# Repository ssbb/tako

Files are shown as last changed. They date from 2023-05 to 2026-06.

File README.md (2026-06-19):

# Tako

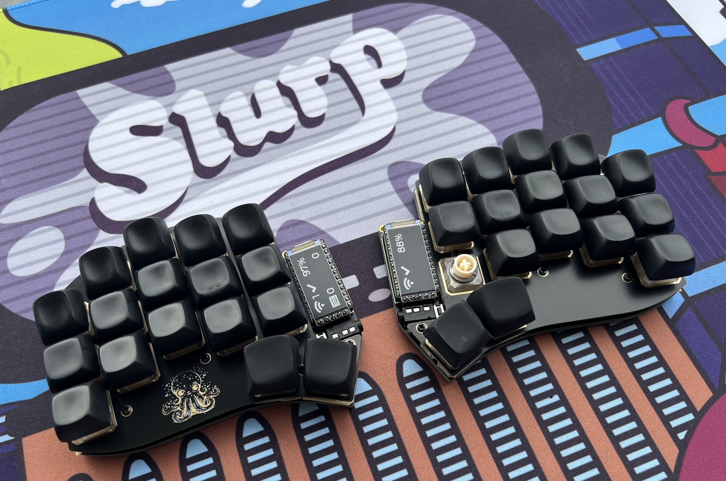
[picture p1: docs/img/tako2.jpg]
Tako Keyboard

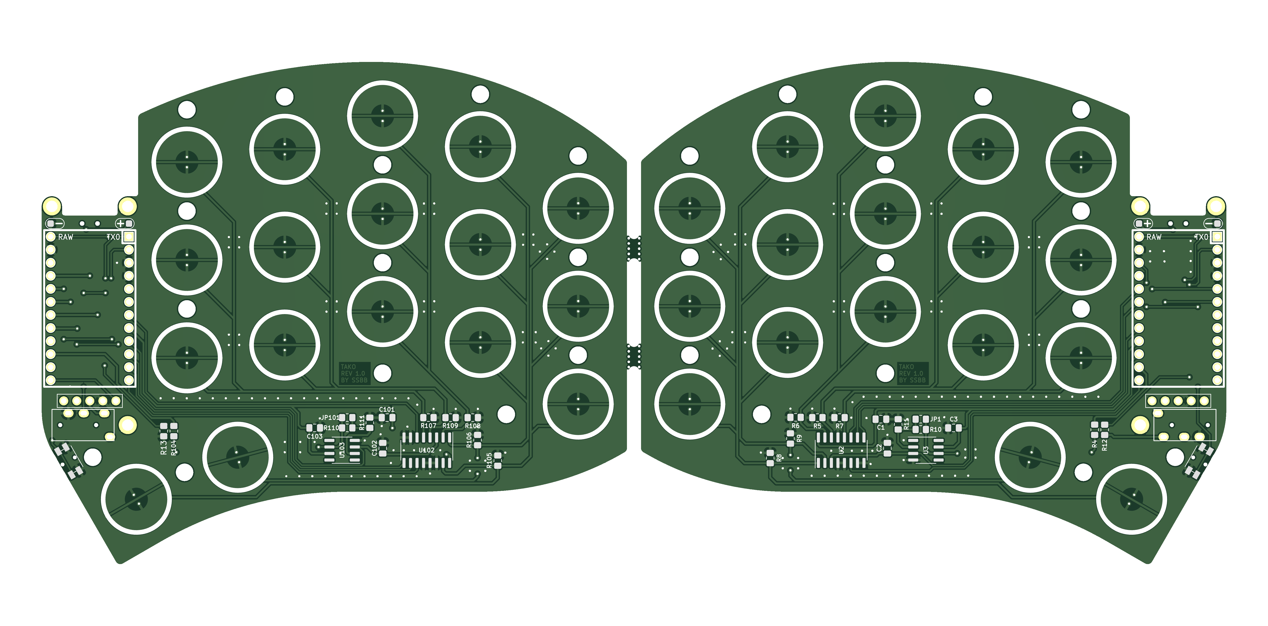
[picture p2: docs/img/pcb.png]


<span>
  
  <a href="https://github.com/ssbb/tako/releases">
    
    
  </a>
  
</span>

Tako is a vertical stagger split keyboard with electrostatic capacitive (EC) non-contact switches.

## Bill Of Materials (BOM)

### Production Files

Depending on which parts you are going to use, make sure to select the proper top plate (OG or NIZ). Ensure you use the correct thickness - the **OG (OEM, Deskeys, etc) plate should be 1.2mm**, and the NIZ should be 1.6mm!

### MCU

RP2040-based boards should be used for wired build - Liatris, Frood, Sea-Picro, Splinky, [etc](https://github.com/qmk/qmk_firmware/blob/master/docs/platformdev_rp2040.md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).

**ATmega32U4 (Pro Micro) won't work.**

#### Wireless

For a wireless build, you can use [nice!nano](https://nicekeyboards.com/nice-nano/). Keep in mind that EC matrix consume significantly more power than mechanical keyboards. An 80mAh battery placed under the MCU will last for about a day only. I don't have exact numbers yet (still waiting for a power profiler), but you will likely need to use a larger battery. Consider using longer standoffs with a 3D-printed or acrylic spacer between the PCB and the bottom plate, and place the battery there.

### Display

5 pins for [nice!view](https://nicekeyboards.com/nice-view/) are exposed. 128x32 OLED can be used on first 4 pins but won't be perfectly centered.

### Components

| Component | Package | Amount | Details |
|---|---|---|---|
| OPA350 | SOIC-8 / SOP-8 | 2 | [LCSC](https://www.lcsc.com/product-detail/_Texas-Instruments-_C13388.html) |
| 74HC4051 | SOIC-8 / SOP-8 | 2 | [LCSC](https://www.lcsc.com/product-detail/_Nexperia-_C9386.html) |
| 100nF Capacitor | 0805 | 4 | [LCSC](https://www.lcsc.com/product-detail/_FH-Guangdong-Fenghua-Advanced-Tech-_C38141.html) |
| 220pF Capacitor | 0805 | 2 | [LCSC](https://www.lcsc.com/product-detail/_Chinocera-_C465163.html) |
| 100&#8486; Resistor  | 0805 | 8 | [LCSC](https://www.lcsc.com/product-detail/_UNI-ROYAL-Uniroyal-Elec-_C17408.html) |
| 1k&#8486; Resistor | 0805 | 2 | [LCSC](https://www.lcsc.com/product-detail/_UNI-ROYAL-Uniroyal-Elec-_C17513.html) |
| 100k&#8486; Resistor | 0805 | 12 | [LCSC](https://www.lcsc.com/product-detail/_UNI-ROYAL-Uniroyal-Elec-_C149504.html) |
| Reset Switch | | 2 | [LCSC](https://www.lcsc.com/product-detail/Tactile-Switches_PANASONIC-EVQPUC02K_C79174.html) |
| PJ-320A | | 2 | *Wired only*. [LCSC](https://www.lcsc.com/product-detail/_XKB-Connectivity-_C2884926.html) |
| 5.1k&#8486; Resitor  | 0805 | 2 | *Wired only*. [LCSC](https://www.lcsc.com/product-detail/Chip-Resistor-Surface-Mount_UNI-ROYAL-Uniroyal-Elec-0805W8F5101T5E_C27834.html) |
| Power Switch | | 2 | *Wireless only*. [LCSC](https://www.lcsc.com/product-detail/Slide-Switches_C-K-PCM12SMTR_C221841.html) |

### Mounting

#### OG Plate

| Part | Amount | Details |
|---|---|---|
| M2x6 Standoff | 16 | Max OD 3.4mm. [Aliexpress](https://aliexpress.com/item/1005003126118423.html?sku_id=12000024241636343) |
| M2x4 Screws | 32 | [Aliexpress](https://aliexpress.com/item/4001248931159.html?sku_id=12000034160900192) |
| M1.6x6 Standoff | 12 | [Aliexpress](https://aliexpress.com/item/33020779625.html?sku_id=12000029334740086) |
| M1.6x4 screws | 24 | [Aliexpress](https://aliexpress.com/item/4001248931159.html?sku_id=12000019001985950) |

#### NIZ Plate

| Part | Amount | Details |
|---|---|---|
| M2x6 Standoff | 28 | Max OD 3.4mm. [Aliexpress](https://aliexpress.com/item/1005003126118423.html?sku_id=12000024241636343) |
| M2x4 Screws | 56 | [Aliexpress](https://aliexpress.com/item/4001248931159.html?sku_id=12000034160900192) |

### EC Parts

| Part | Amount |
|---|---|
| Housings | 34 |
| Domes | 34 |
| Conical springs | 34 |
| Sliders | 34 |
| Silencing rings | 34 |

- If you going to use DES V3/Carrot domes then it's recommended to get DES Volcano springs to avoid sping crunch.
- Silencing rings are recommended for DES parts. If you want the same key travel as HHKB Type-S with DES housings and DES sliders then you should get #7 rings.

Some EC vendors:

- [deskeys](https://deskeys.io/)
- [NIZ Store](https://www.nizkeyboard.com/products/2019-new-niz-ec-switch)
- [Beekeeb (NIZ)](https://shop.beekeeb.com/product/niz-ec-switch/)
- YMDK [Housings](https://aliexpress.com/item/1005005724051113.html), [Sliders](https://aliexpress.com/item/1005005721976294.html) and [Domes](https://aliexpress.com/item/1005005721050116.html)

**You can only use MX-compatible sliders due to the housing orientation.** [See details](./docs/housing_orientation.md).

NIZ sliders are MX-compatible by default.

## Build Guide

[Build Guide](./docs/buildguide.md)

## Case

There's an awesome case for Tako designed by [GofranChang](https://github.com/GofranChang). Check it out over at [GofranChang/TakoNest](https://github.com/GofranChang/TakoNest) - huge thanks for putting this together! 🙌

## Firmware

- [QMK Firmware](https://github.com/ssbb/qmk_firmware/tree/master/keyboards/ssbb/tako)
- [ZMK Firmware](https://github.com/ssbb/tako-config)

## Thanks

Special thanks to [Cipulot](https://github.com/Cipulot/) for all the work on EC keyboards and assistance.

- [jimmerricks](https://github.com/jimmerricks/swoop) for Swoop
- [duckyb](https://github.com/duckyb/urchin) for Urchin I was inspired by
- Awesome [Pete Johanson](https://github.com/petejohanson) for assistance
- [kanru](https://github.com/kanru) for his work on Zephyr driver for HHKB which I used for reference

## Support

Check #ssbb channel on Absolem Club discord. [Join](https://discord.gg/WKmtMGwQtC)

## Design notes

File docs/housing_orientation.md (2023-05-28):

Topre housings are designed for row stagger:

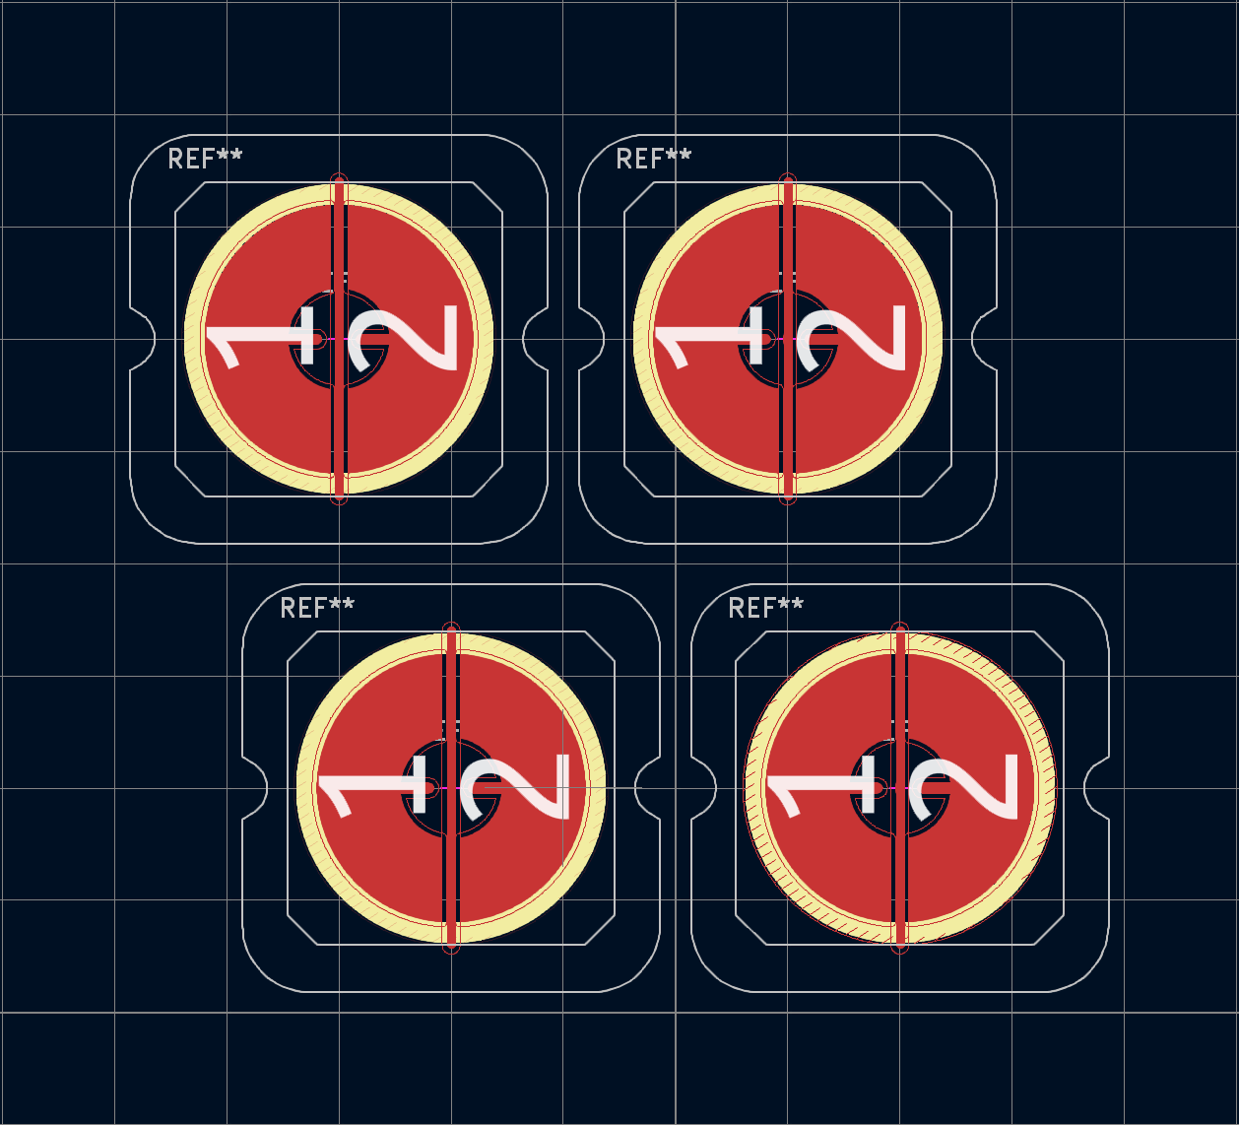
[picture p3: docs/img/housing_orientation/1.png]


You can put some screws between housings (see rounded cutouts at the sides) and dome strips designed to be used like this as well. But Tako is a column-staggered keyboard. And when we do the same we would get something like this:

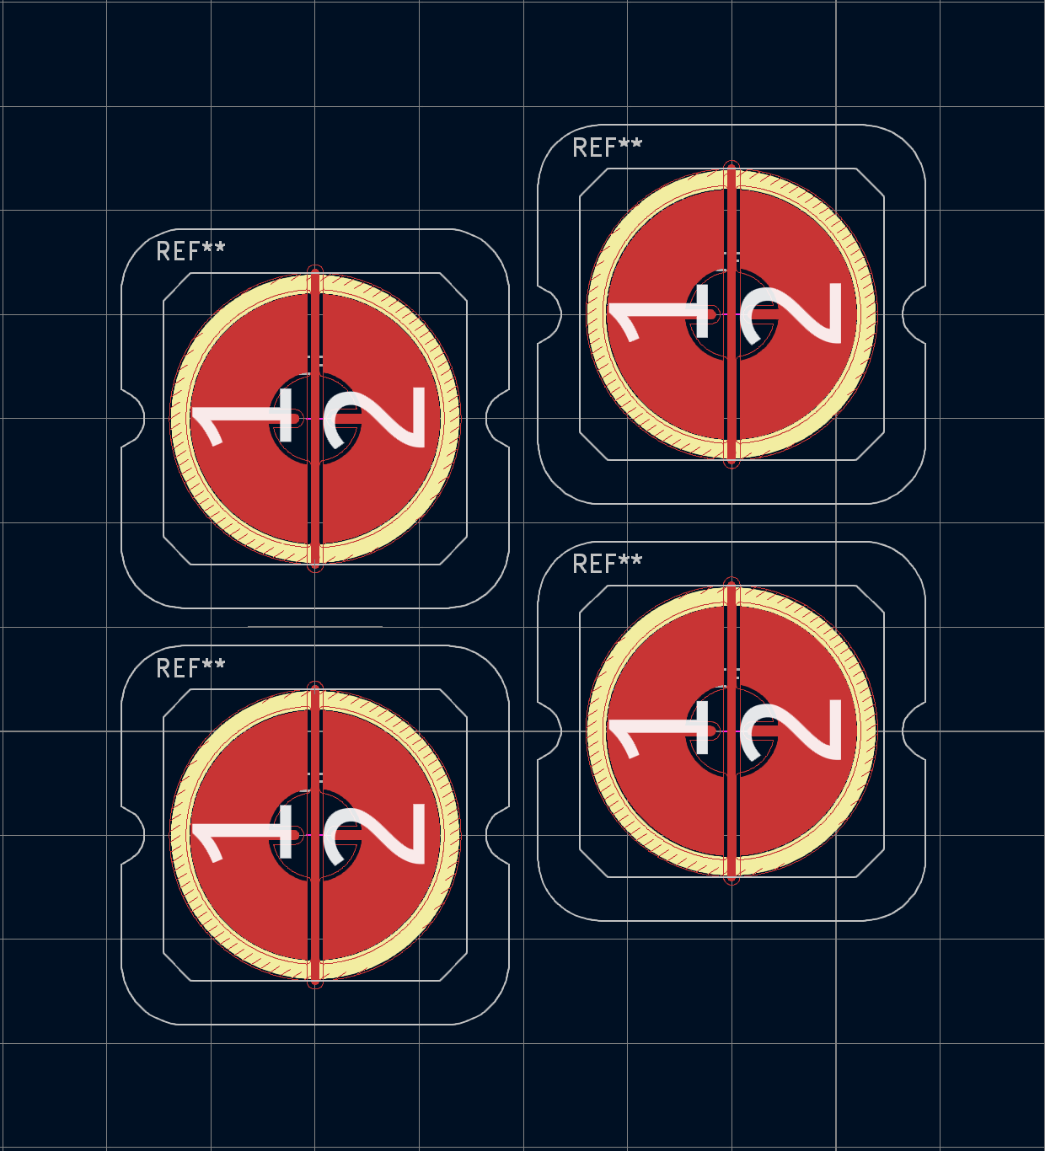
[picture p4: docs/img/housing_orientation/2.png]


Now, there is no space for screws, and you can't use dome strips due to the misaligned rows. So it's logical to change the housing orientation, making columns the new "rows".

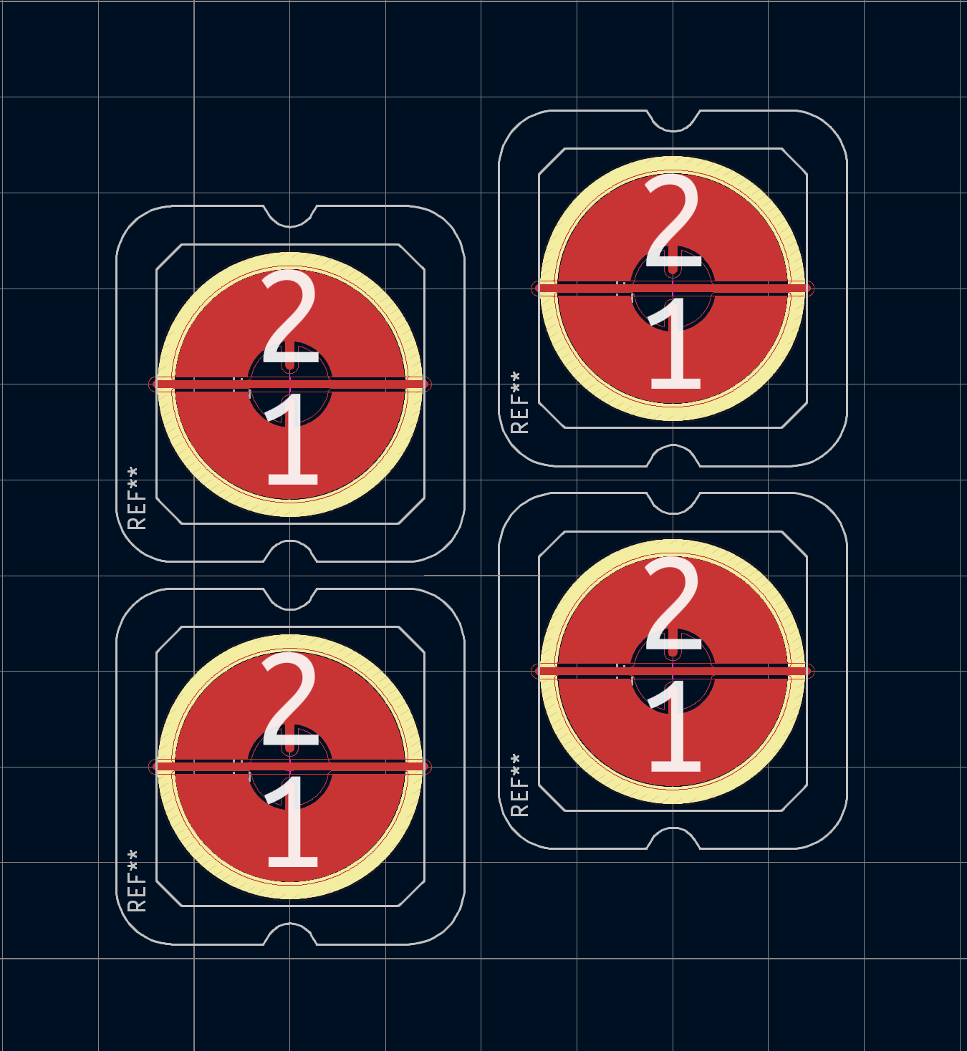
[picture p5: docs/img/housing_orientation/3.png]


And thats what I did in the default top plate. By fact we using housings like they designed to be used but for columns instead of rows. However, unlike in the MX world, Topre sliders only allow keycaps to be installed in one direction. So when using Topre sliders with rotated housings, your keycaps will end up at a 90-degree angle.

I don't think it's an issue at all since Topre-compatible keycaps are much rarer than MX ones. Therefore, it's unlikely that anyone making a 34-keyboard will need to use original Topre keycaps.

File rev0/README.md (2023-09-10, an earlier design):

# Tako rev0

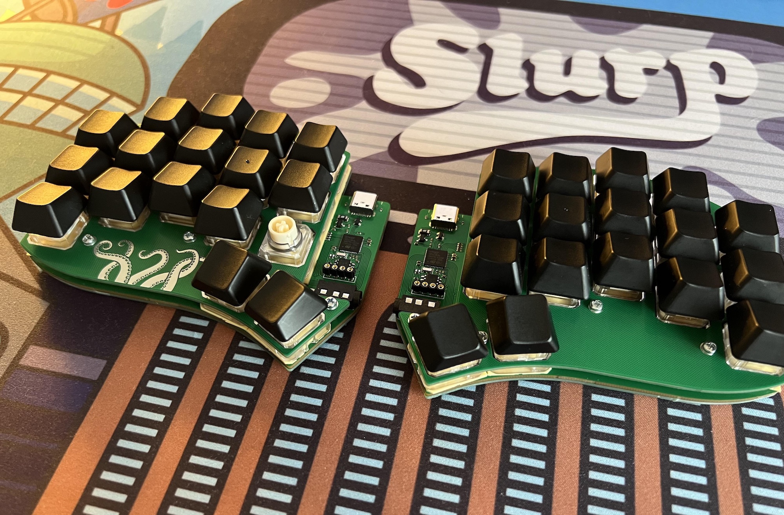
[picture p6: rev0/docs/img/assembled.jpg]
PCB Preview


> **Warning**
> I warn against building this version since after working on new version for some time I realized that some things were done wrong so I strictly suggest to build rev1. I am not planning to support this so it can't be considered as PCBA alternative to rev1.

---

## Table of Contents

- [Features](#features)
- [Caveats](#caveats)
- [BOM](#bom)
- [Build guide](#build-guide)
- [Firmware](#firmware)

## Features

- Onboard USB-C with ESD protection
- STM32F4x1 MCU
- Actuation Point Changer
- USART Full-duplex
- [OLED](./docs/img/assembled_oled.jpg) support

## Caveats

- No tenting puck support since there is no space between housings for screw holes. But could be done on bottom plate with different case design.
- No reset button (the one you see on the photo is a STM32 Boot0)

## BOM

### Assembled version

| Part | Amount | Details |
| --- | --- | --- |
| Assembled PCB  | 1 | 1.6mm |
| Top plate | 2 | 1.2mm thickness! |
| Bottom plate | 2 | 1.6mm |
| M2x6 standoffs | 16 | Max OD 3.3mm. [This](https://aliexpress.com/item/32975966103.html?sku_id=66665375911) and [this](https://aliexpress.com/item/1005003126118423.html?sku_id=12000024241636343) confirmed to work. |
| M2x4 screws | 32 | |
| PJ-320A | 2 | Audio jack |
| TRRS Cable | 1 | |

> **Warning** **Top plate should be 1.2mm thick!**

#### Optional

| Part | Amount |
| --- | --- |
| 128x32 OLED  | 2 |
| OLED Sockets | 2 |

#### Optional mounting

There are also mounting holes between housings on 1, 3, and 5 columns. They are not required, and it should be fine not to use them. However, in case you experience some "squishing" sounds, especially on the homerow, it is likely that the housings are not sitting properly on the PCB. You should try to re-assemble keyboard first to ensure domes and springs aligned properly.

If this does not help, then you will need to add mounting somewhere at the center of the keyboard. There is no space for M2 standoffs between the housings, so you should use M1.6 (max OD is 2.5mm) or just a long M2 screw (around 11mm) with a nut on the bottom plate.

| Part | Amount | Details |
| --- | --- | --- |
| M1.6x6 standoffs | 12 | [Aliexpress](https://aliexpress.ru/item/4000582961951.html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) |
| M1.6x4 screws | 24 | |

## Build guide

- [Build guide](./docs/buildguide_assembled.md)

## Firmware

Only QMK is supported.

- [Assembled version firmware](https://github.com/ssbb/qmk_firmware/tree/master/keyboards/ssbb/tako)

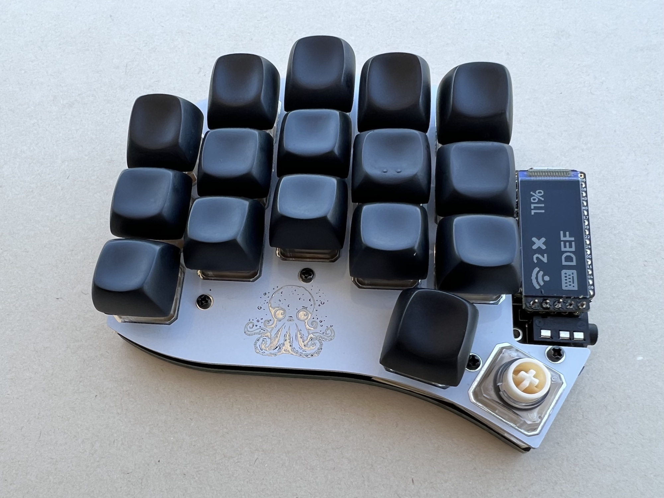
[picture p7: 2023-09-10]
docs/img/tako.jpg

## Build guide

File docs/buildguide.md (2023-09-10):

# Build Guide

## Preparation

The PCB is fabricated as a panel, so the first step is to gently break it in half."

## Solder components

Place all the components using the interactive BOM. You can solder them in any order; the only requirement is to solder the reset button before the TRRS jack.

Orientation only matters for the `OPA350` and `74HC4051` chips (`U2`, `U3`, `U102`, and `U103`). You should align the dot on the chip with the long line on the PCB. For the rest (resistors and capacitors), orientation does not matter.

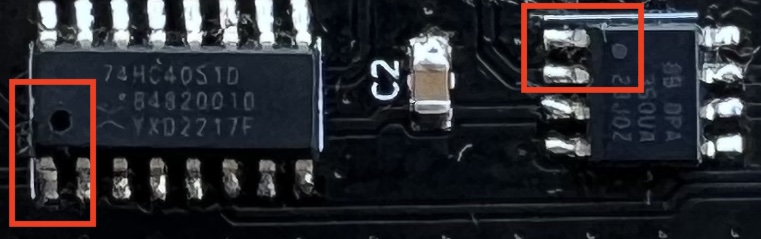
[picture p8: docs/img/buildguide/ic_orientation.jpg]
IC Orientation


Keep in mind that the left and right sides are not exact mirrors, so refer to the PCB and interactive BOM (iBOM) when soldering.

`JP1` and `JP101` are used to adjust OpAmp gain and can be ignored during the build.

`R12` and `R112` are used for keymap configuration in QMK, and you can ignore them for the wireless build.

If you have no experience in soldering SMD components, you can check out the [SMD Soldering Tutorial](https://www.youtube.com/watch?v=fYInlAmPnGo) video.

Solder the MCU and display sockets, battery, and power switch (for wireless) at this step as well. At the end, your assembly should resemble the following (note that you don't need to solder the TRRS jack for wireless):

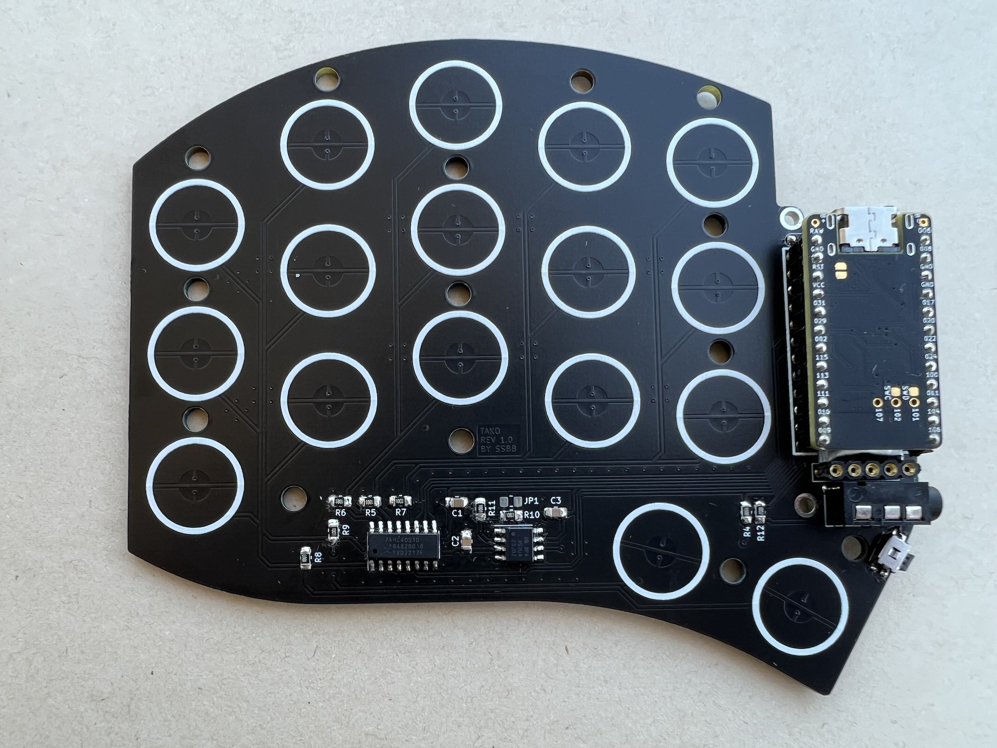
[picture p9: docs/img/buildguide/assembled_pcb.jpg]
Assembled PCB


## Test

Now, you can test the PCB before proceeding to ensure everything has been done correctly. Flash the firmware (the release contains default firmware for both QMK and ZMK) and open the console (it's enabled by default):

- QMK: https://github.com/qmk/qmk_firmware/blob/master/docs/faq_debug.md
- ZMK: https://zmk.dev/docs/development/usb-logging#viewing-logs

You should see a matrix scan with readings, and the values should change when you place your finger on the EC pads.

## Top plate

Now that you're sure everything works, it's time to prepare the top plate.

First of all, you should install the standoffs. If you're building an OG plate, use M1.6 standoffs for the six yellow-marked positions, and the rest should be M2. For the NIZ plate, all standoffs should be M2. Then, proceed to install the housings. Refer to the red mark for the correct orientation. Finally, put sliders (with optional silencing rings installed) into the housings. You can lube slider rails prior of installing them.

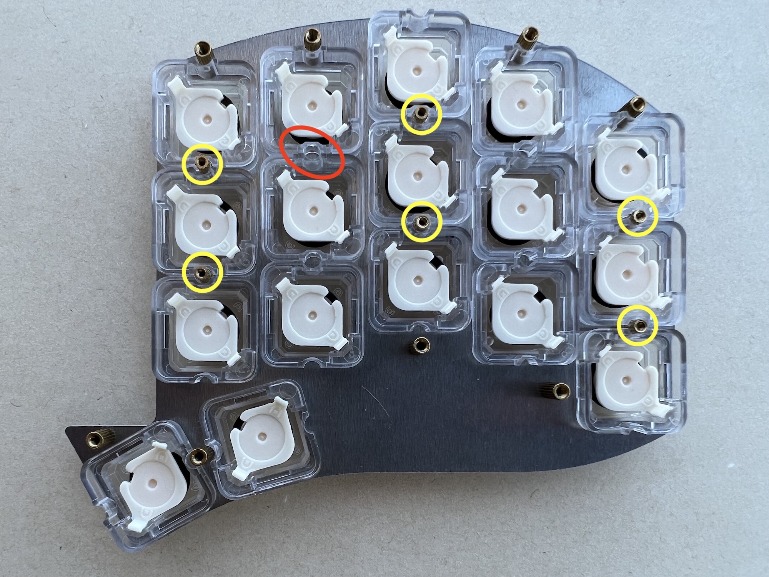
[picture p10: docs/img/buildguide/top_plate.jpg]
Top Plate


Now, cut your domes so you have five 3x strips and two individual domes (or 10 and 4 for both sides). While holding top plate with one hand - place them to the housings with the other hand. Make sure all of them are aligned well and then put springs inside the domes.

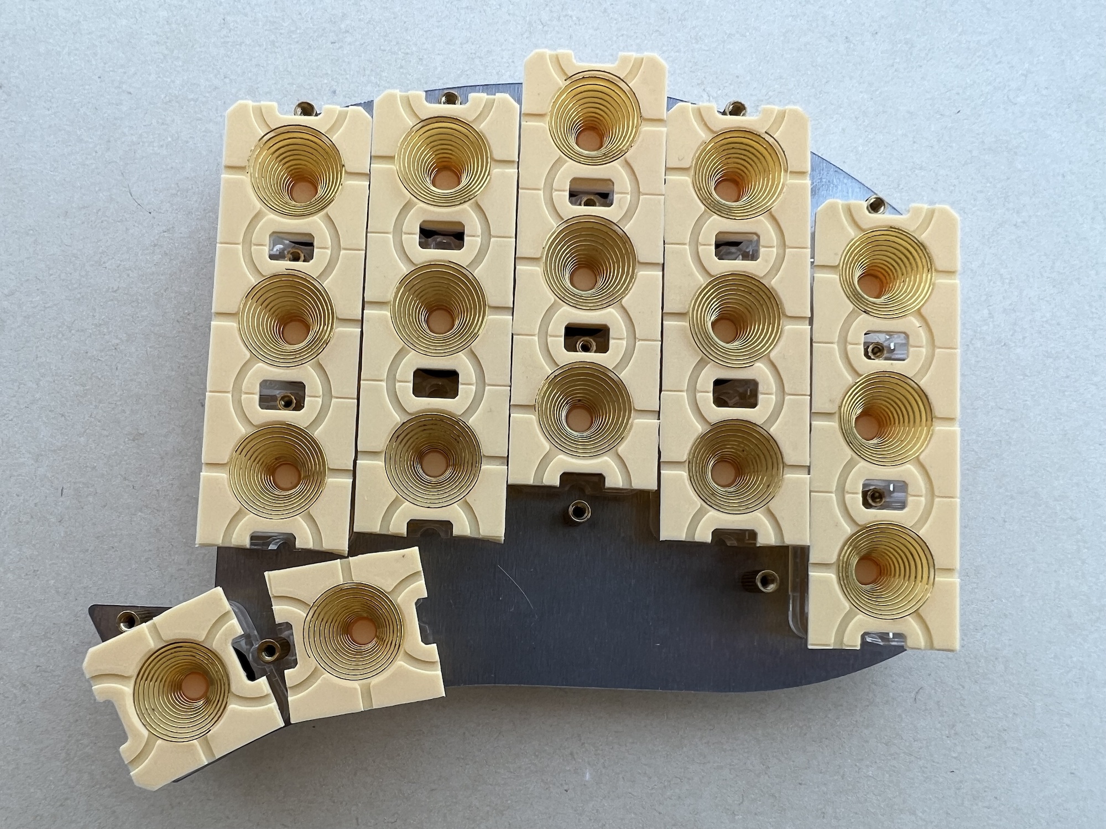
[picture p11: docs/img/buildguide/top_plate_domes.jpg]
Top Plate Domes


## Final assembly

Now, cover the top plate with the assembled PCB, and then place the bottom plate on top of it. Secure everything with screws, remembering to use M1.6 screws for the six center standoffs when building the OG plate.

Now, you should connect the keyboard and check the console again. Make sure that all the readings are relatively similar. If the readings on all the keys are around 100, and on one of them, it's 500, then something is off. Also, check that the readings increase for each key when you press it. In case of any problems, in 99% of cases, it's a spring misalignment, so you should disassemble the keyboard, align the domes and springs, and assemble it again.

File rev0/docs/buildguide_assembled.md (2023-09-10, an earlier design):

# TAKO BUILD GUIDE (REV0)

## PREPARATION

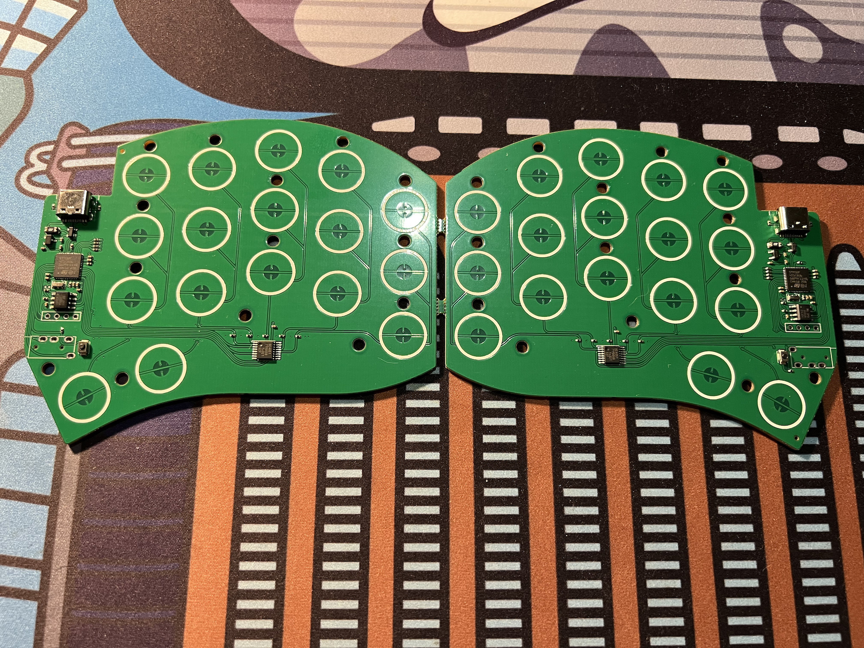
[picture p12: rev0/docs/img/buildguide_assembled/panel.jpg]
Panel


You'll receive a PCB as a panel, so the first thing you need to do is gently break it in the middle and clean the PCB edges with sandpaper.

## TRRS JACK AND OLED SOCKET

> **Warning**
> Please check the bottom plate. If you printed the first version of this, which had an issue with the TRRS cutout, then you either need to drill the missing holes or cut the TRRS legs in half before soldering, so the PCB lies flat. [See details](./fixes/fix_bottom_plate_cutouts.md).

There are only a few components you need to solder - TRRS jack and optional OLED sockets. You can use masking tape to make this process easier.

At the end, you should have something like this:

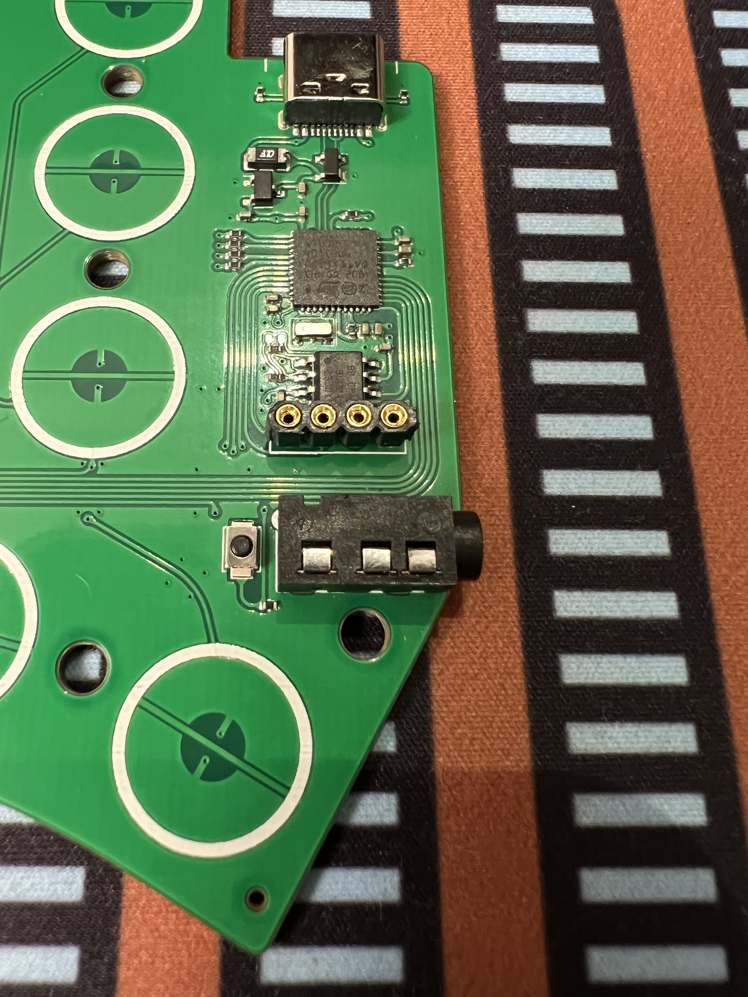
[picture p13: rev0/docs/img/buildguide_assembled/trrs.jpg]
TRRS Jack Soldering


## STANDOFFS

Screw M2x6mm standoffs at the positions shown in the image below.

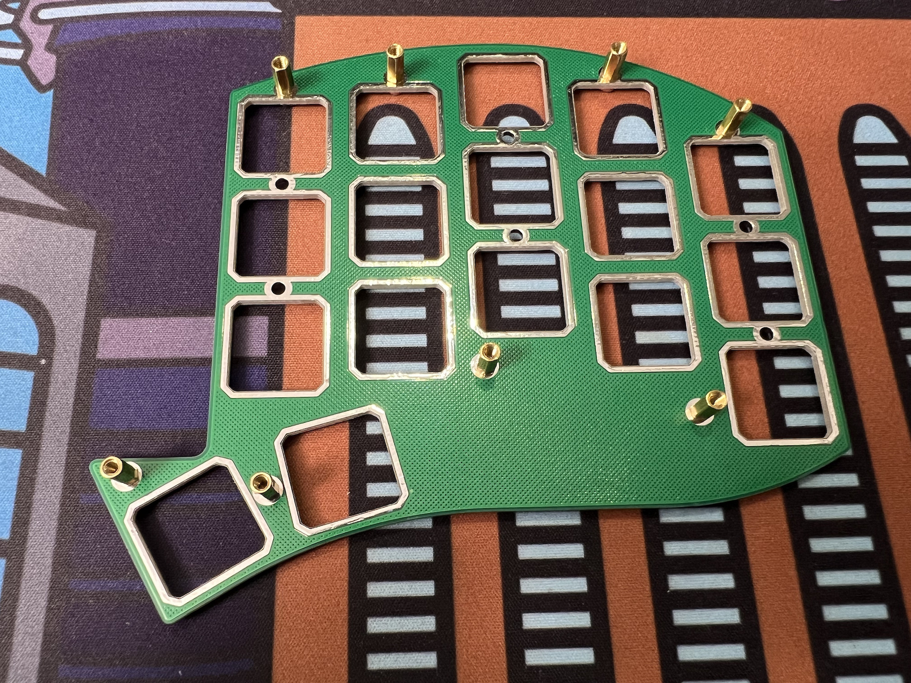
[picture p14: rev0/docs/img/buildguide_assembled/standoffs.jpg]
Standoffs Installation


Unused mounting holes at the center won't work with M2 standoffs and should be used for optional mounting with something like M1.6 (maximum standoff OD is 2.5mm). Personally, I am not using them due to the low availability of M1.6, but they could be used to improve contact between the PCB and housings. More mounting points are always better for EC keyboards.

## HOUSINGS

Press the housings into the plate. They are not square, so you can only do it in one direction - confirm with the image below. They should "click" into place when properly fitted.

> **Warning**
> If you are installing housings for the second half, please double-check that the plate orientation is correct. You don't want to end up with two plates that can only be used for the left half.

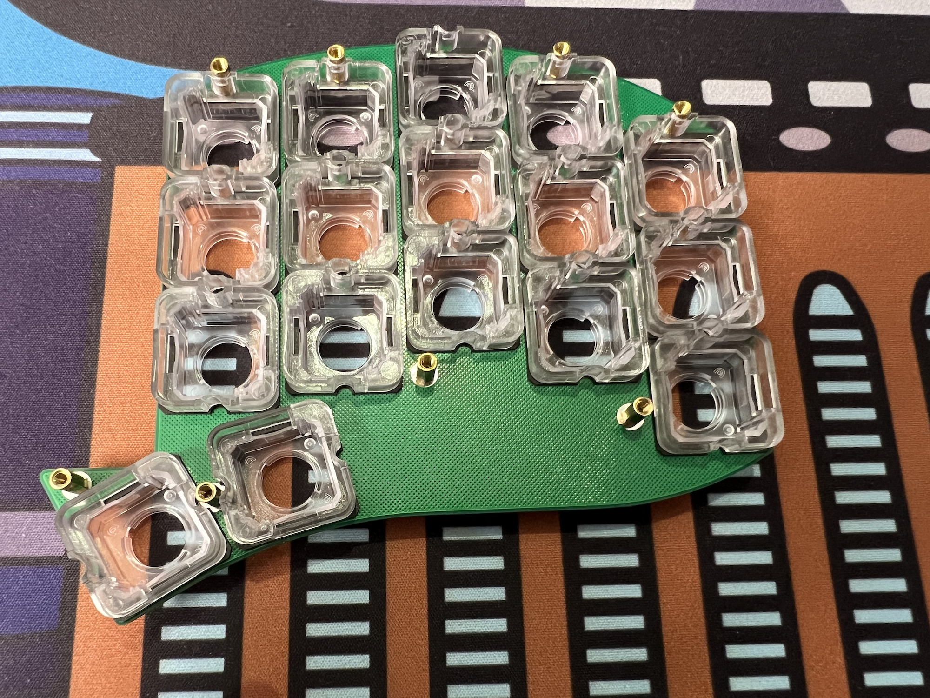
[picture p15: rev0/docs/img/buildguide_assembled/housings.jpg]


After you have installed all the housings, take a look at the back side. There is a good chance that some of the walls (marked in red) may be bent, as shown in the image above (where almost all of them are bent due to housing gasket usage). Just press on those walls with your thumb, and they should click and become straight (it may not be that simple with housing gaskets). It's important to do this so that the housings are not deformed and the sliders can move freely.

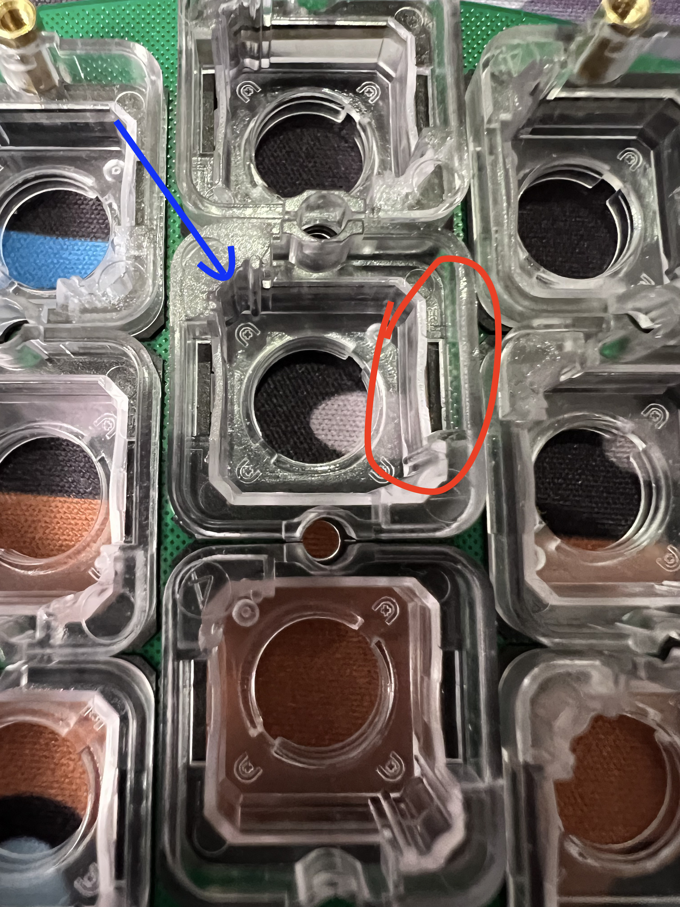
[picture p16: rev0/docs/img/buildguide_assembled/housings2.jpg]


### LUBE (OPTIONAL)

You could lube the housing rails (where the blue arrow points in the image above) with something like 205g0. Some people prefer to lube them, while others do not - decide for yourself.

## SLIDERS

First, add a silencing ring to each slider:

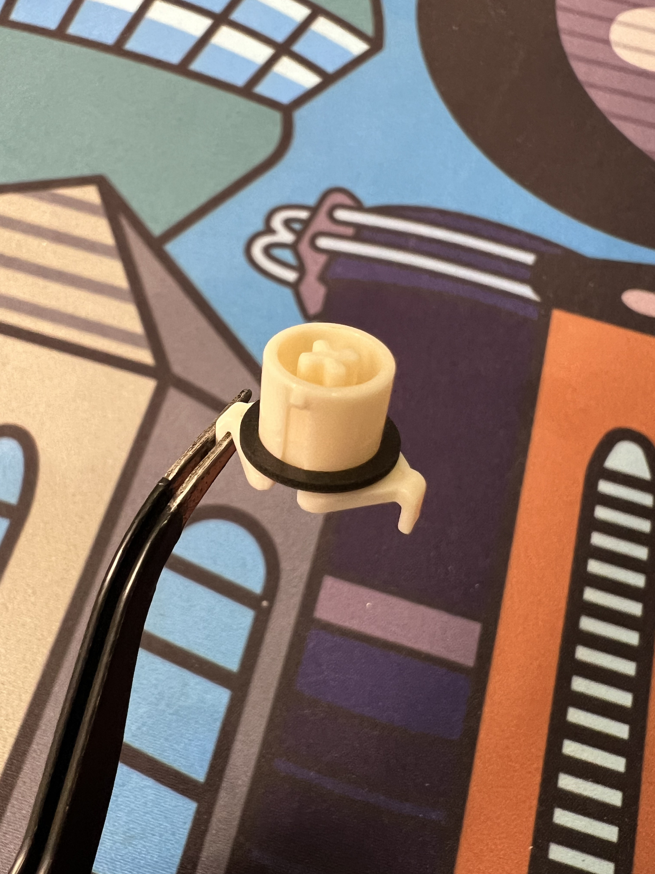
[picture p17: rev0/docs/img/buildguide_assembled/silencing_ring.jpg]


Then, put them into the housings. Note the orientation of the slider rails and housing rails:

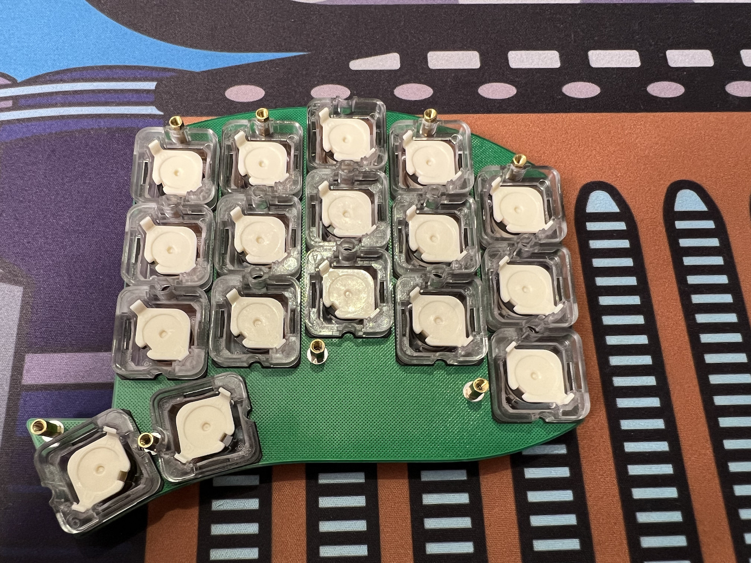
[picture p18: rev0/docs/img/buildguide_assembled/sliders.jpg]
Sliders


## DOMES

If you have domes in strips, you should cut them into sets of three. In total, you'll need 10 strips with 3 domes each and 4 single domes.

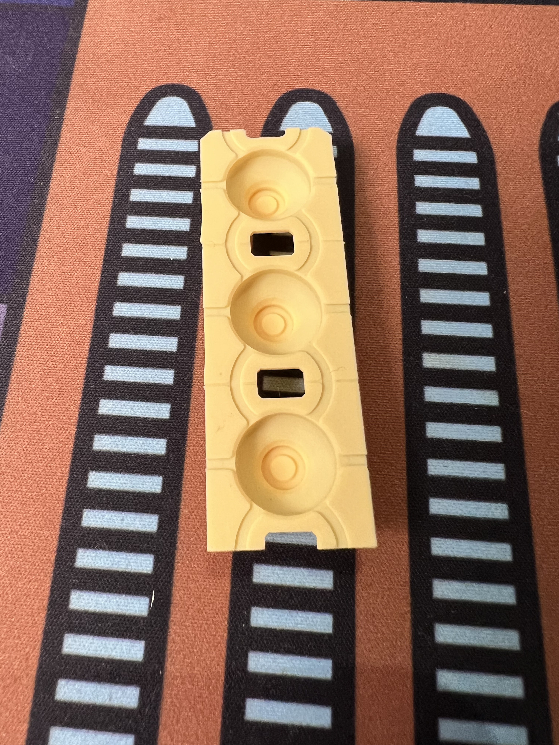
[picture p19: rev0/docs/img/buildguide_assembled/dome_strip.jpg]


Then, place them over the housings so that you get something like this:

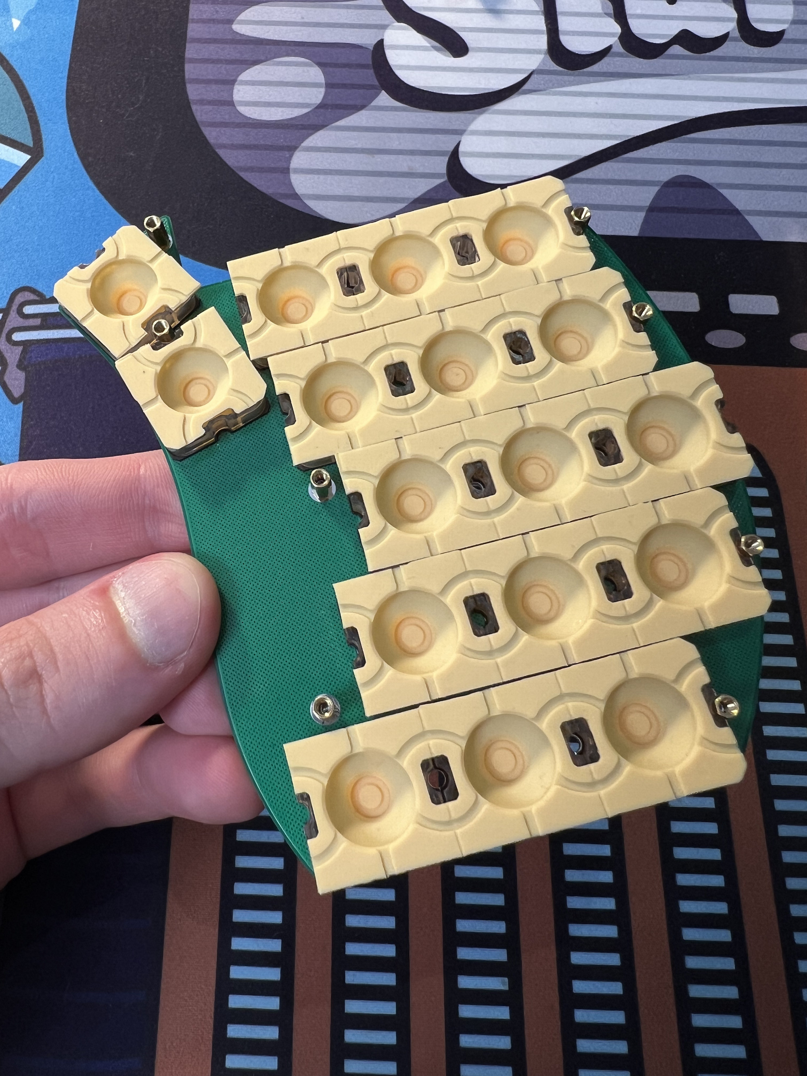
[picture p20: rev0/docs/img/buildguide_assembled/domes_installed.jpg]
Domes installed


Make sure to align them properly so that there are no instances of one dome overlapping another, etc. Also, from this point on, you should keep the keyboard in your hand or use something as support to prevent the keys from being pressed.

## CONICAL SPRINGS

Now, add a spring into each dome and align it. It should be centered and stay within the dome. See the image below as a reference.

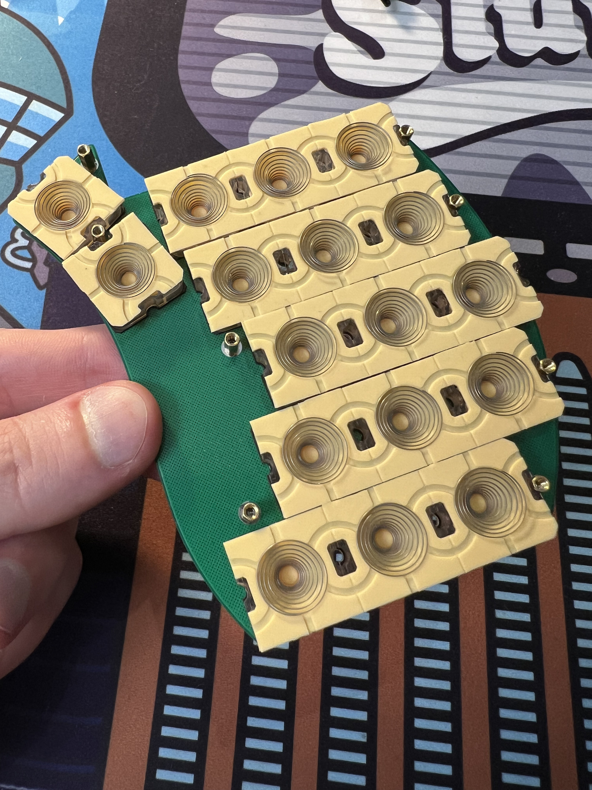
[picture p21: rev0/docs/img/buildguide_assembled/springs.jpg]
Springs


## PCB AND BOTTOM PLATE

Now, place the PCB over the domes and then the bottom plate over it (you can just stack the PCB and bottom plate and place them together).

Finally, screw the bottom plate to the standoffs. The standoffs are slightly shorter than the distance between the top and bottom plates (around 6.3mm vs 6mm). You don't need to screw them all the way to the end and bend the top plate, just make sure everything is fixed in place.

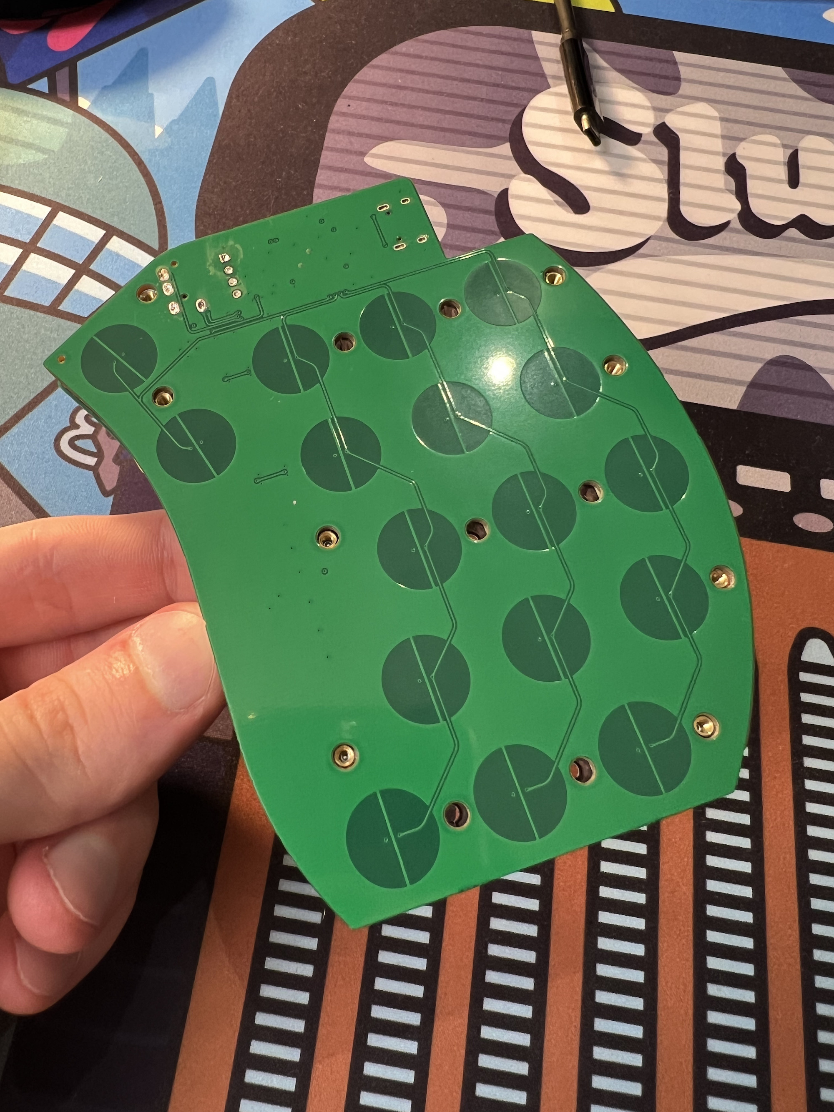
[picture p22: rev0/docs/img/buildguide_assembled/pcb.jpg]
PCB


> **Note**
> There are no cutouts on the bottom plate in my photo because I forgot about them in the first prototype and just cut the socket legs instead.

Now, you can add some bumpons to the bottom plate:

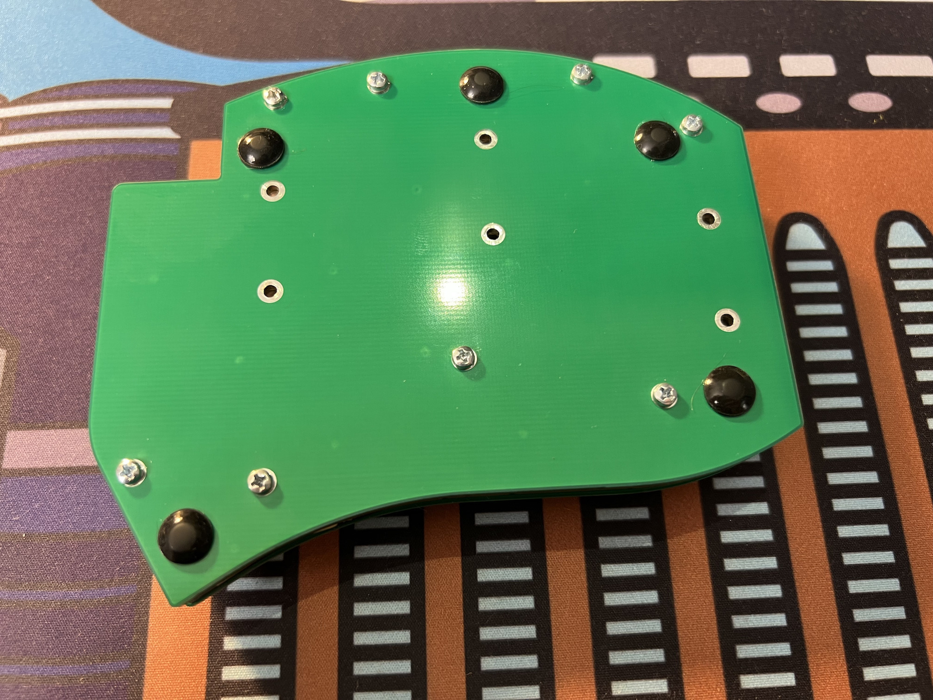
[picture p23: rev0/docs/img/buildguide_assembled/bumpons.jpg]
Bumpons


## RESULT

Now, you should have something like this. You did it, great job!

Repeat the same process for the second half.

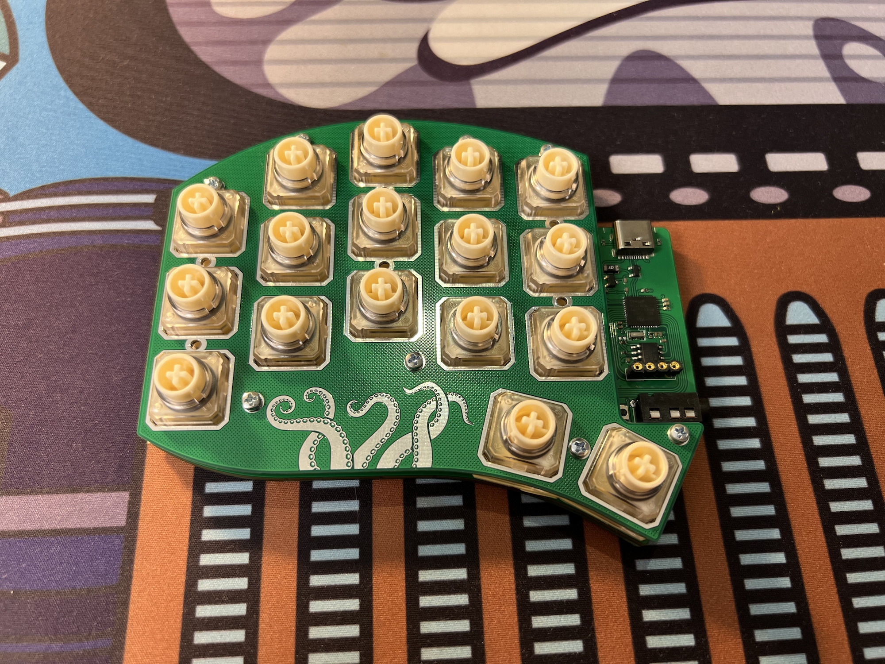
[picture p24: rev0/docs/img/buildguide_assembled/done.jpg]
Done keyboard


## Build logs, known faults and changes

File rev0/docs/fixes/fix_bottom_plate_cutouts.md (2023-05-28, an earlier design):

# Fix Bottom Plate Cutouts

I'm sorry to say that the initial version of the bottom plate had non-reversible cutouts for the TRRS socket. If you have already printed it, it will only work for one side, and you need to fix it for the other side.

There are a few ways to do it:

1. **Drill missing holes**
   This is probably the best way if you have a drill. Just stack the PCB and the bottom plate, mark the positions with a pen, and then drill the missing holes.

2. **Cut TRRS socket legs**
   You could cut the legs of the TRRS socket in half and then solder them inside the holes to keep the PCB bottom flat. That's what I actually did and showed in the build guide.

3. **Use foam**
   You could place foam between the PCB and the bottom plate - something around 2mm should work. This will increase the overall height, and you should use taller standoffs.

   The standoff height should be less than the whole stack. By default, they are 6mm (~4.7mm spacing between the PCB and the top plate + 1.6mm PCB = 6.3mm). Depending on the foam density, you could either add the foam thickness to the standoff length or use a slightly smaller one (so 7mm or 8mm should work with 2mm foam).

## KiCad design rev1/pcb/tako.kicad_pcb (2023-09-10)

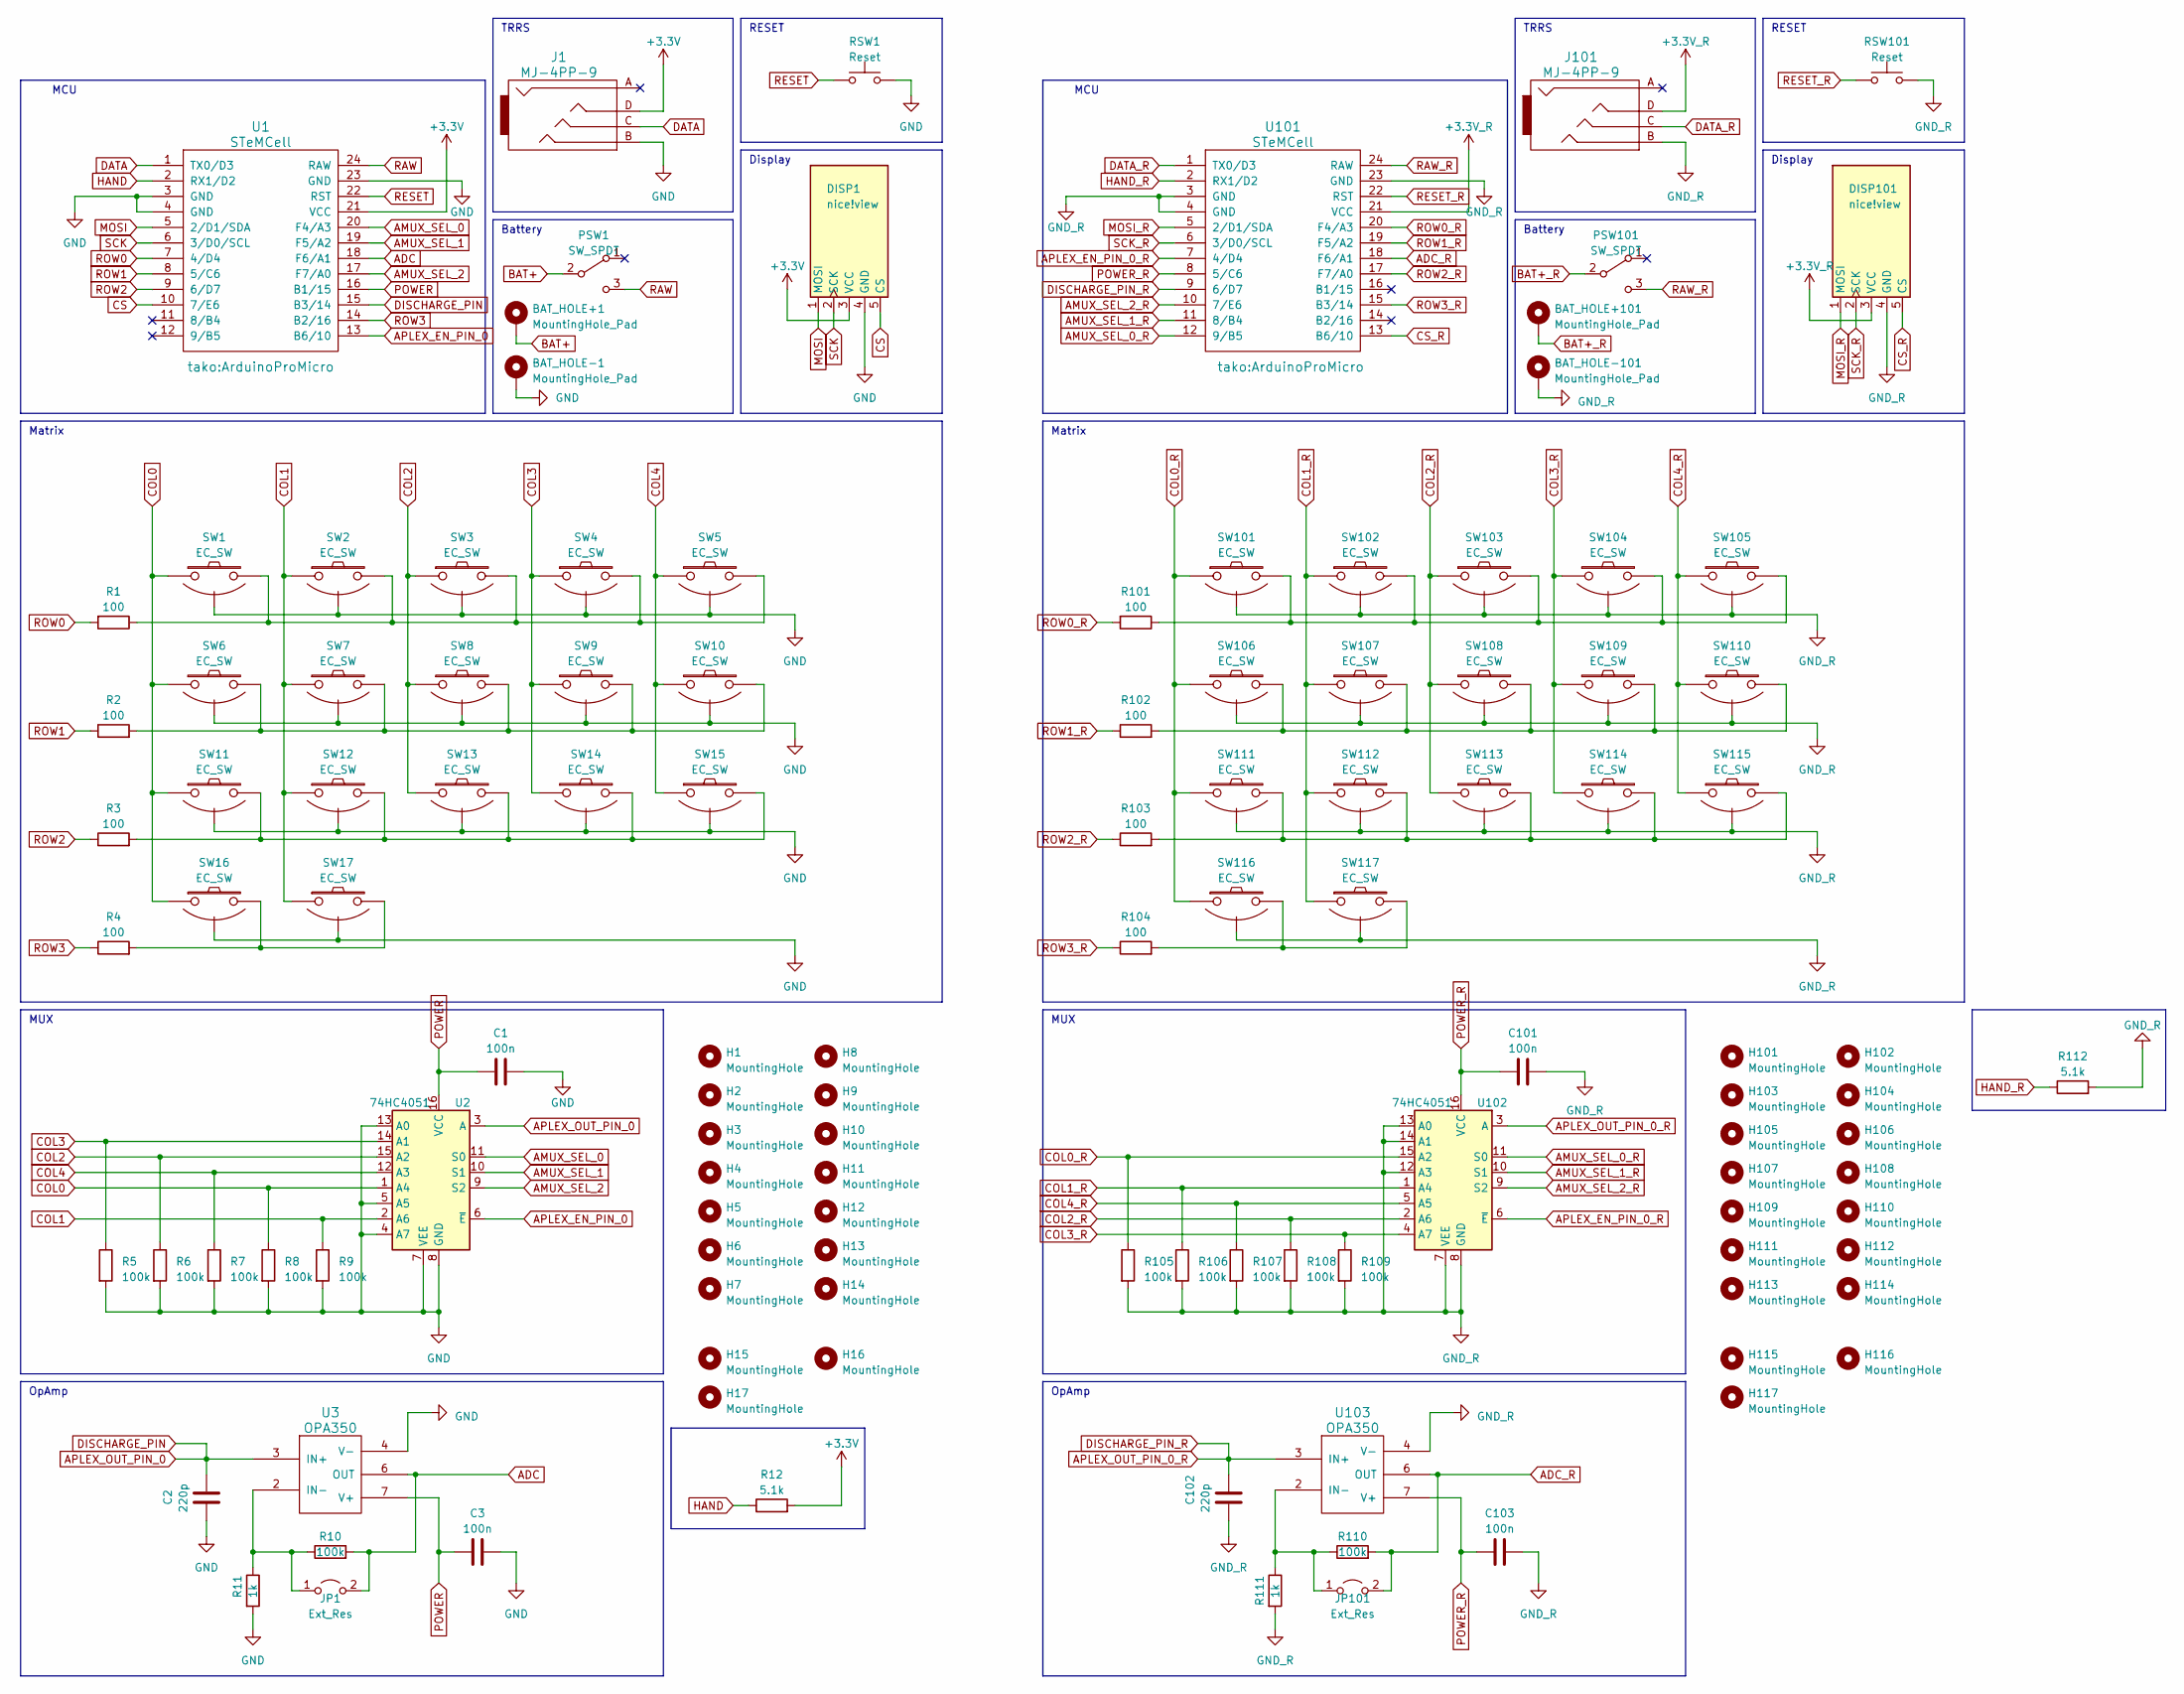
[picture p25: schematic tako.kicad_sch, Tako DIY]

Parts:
BAT_HOLE+1, BAT_HOLE+101: MountingHole_Pad; bat_pin+
BAT_HOLE-1, BAT_HOLE-101: MountingHole_Pad; bat_pin-
C1, C3, C101, C103: 100n; C_0805_2012Metric_Pad1.18x1.45mm_HandSolder
C2, C102: 220p; C_0805_2012Metric_Pad1.18x1.45mm_HandSolder
DISP1, DISP101: nice!view; nice_view
H1, H2, H3, H4, H5, H6, H7, H8, H9, H10, H11, H12, H13, H14, H101, H102, H103, H104, H105, H106, H107, H108, H109, H110, H111, H112, H113, H114: MountingHole; MountingHole_3.4mm
H15, H16, H17, H115, H116, H117: MountingHole; M2_hole_3.5mm
J1, J101: MJ-4PP-9; TRRS-PJ-320A
JP1, JP101: Ext_Res; R_0805_2012Metric_Pad1.20x1.40mm_HandSolder
PSW1, PSW101: SW_SPDT; SW_SPDT_SMD_PCM12
R1, R2, R3, R4, R101, R102, R103, R104: 100; R_0805_2012Metric_Pad1.20x1.40mm_HandSolder
R5, R6, R7, R8, R9, R10, R105, R106, R107, R108, R109, R110: 100k; R_0805_2012Metric_Pad1.20x1.40mm_HandSolder
R11, R111: 1k; R_0805_2012Metric_Pad1.20x1.40mm_HandSolder
R12, R112: 5.1k; R_0805_2012Metric_Pad1.20x1.40mm_HandSolder
RSW1, RSW101: Reset; Panasonic_EVQPUL_EVQPUC
SW1, SW2, SW3, SW4, SW5, SW6, SW7, SW8, SW9, SW10, SW11, SW12, SW13, SW14, SW15, SW101, SW102, SW103, SW104, SW105, SW106, SW107, SW108, SW109, SW110, SW111, SW112, SW113, SW114, SW115: EC_SW; ecs_pad_1U_no_ring
SW16, SW17, SW116, SW117: EC_SW; ecs_pad_1U_no_ring_90deg
U1, U101: STeMCell; ArduinoProMicro
U2, U102: 74HC4051; SOIC-16_3.9x9.9mm_P1.27mm
U3, U103: OPA350; SOIC-8_3.9x4.9mm_P1.27mm

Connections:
+3.3V: DISP1.3 (VCC), J1.D, R12.2, U1.21 (VCC)
+3.3V_R: DISP101.3 (VCC), J101.D, U101.21 (VCC)
ADC: JP1.2 (B), R10.2, U1.18 (F6/A1), U3.6 (OUT)
ADC_R: JP101.2 (B), R110.2, U101.18 (F6/A1), U103.6 (OUT)
AMUX_SEL_0: U1.20 (F4/A3), U2.11 (S0)
AMUX_SEL_0_R: U101.12 (9/B5), U102.11 (S0)
AMUX_SEL_1: U1.19 (F5/A2), U2.10 (S1)
AMUX_SEL_1_R: U101.11 (8/B4), U102.10 (S1)
AMUX_SEL_2: U1.17 (F7/A0), U2.9 (S2)
AMUX_SEL_2_R: U101.10 (7/E6), U102.9 (S2)
APLEX_EN_PIN_0: U1.13 (B6/10), U2.6 (~E)
APLEX_EN_PIN_0_R: U101.7 (4/D4), U102.6 (~E)
APLEX_OUT_PIN_0: C2.1, U1.15 (B3/14), U2.3 (A), U3.3 (IN+)
APLEX_OUT_PIN_0_R: C102.1, U101.9 (6/D7), U102.3 (A), U103.3 (IN+)
BAT+: BAT_HOLE+1.1, PSW1.2 (B)
BAT+_R: BAT_HOLE+101.1, PSW101.2 (B)
COL0: R8.1, SW1.1, SW6.1, SW11.1, SW16.1, U2.1 (A4)
COL0_R: R105.1, SW101.1, SW106.1, SW111.1, SW116.1, U102.15 (A2)
COL1: R9.1, SW2.1, SW7.1, SW12.1, SW17.1, U2.2 (A6)
COL1_R: R106.1, SW102.1, SW107.1, SW112.1, SW117.1, U102.1 (A4)
COL2: R6.1, SW3.1, SW8.1, SW13.1, U2.15 (A2)
COL2_R: R108.1, SW103.1, SW108.1, SW113.1, U102.2 (A6)
COL3: R5.1, SW4.1, SW9.1, SW14.1, U2.14 (A1)
COL3_R: R109.1, SW104.1, SW109.1, SW114.1, U102.4 (A7)
COL4: R7.1, SW5.1, SW10.1, SW15.1, U2.12 (A3)
COL4_R: R107.1, SW105.1, SW110.1, SW115.1, U102.5 (A5)
CS: DISP1.5 (CS), U1.10 (7/E6)
CS_R: DISP101.5 (CS), U101.13 (B6/10)
DATA: J1.C, U1.1 (TX0/D3)
DATA_R: J101.C, U101.1 (TX0/D3)
GND: BAT_HOLE-1.1, C1.2, C2.2, C3.2, DISP1.4 (GND), J1.B, R5.2, R6.2, R7.2, R8.2, R9.2, R11.2, RSW1.2, SW1.3 (SG), SW2.3 (SG), SW3.3 (SG), SW4.3 (SG), SW5.3 (SG), SW6.3 (SG), SW7.3 (SG), SW8.3 (SG), SW9.3 (SG), SW10.3 (SG), SW11.3 (SG), SW12.3 (SG), SW13.3 (SG), SW14.3 (SG), SW15.3 (SG), SW16.3 (SG), SW17.3 (SG), U1.3 (GND), U1.4 (GND), U1.23 (GND), U2.4 (A7), U2.5 (A5), U2.7 (VEE), U2.8 (GND), U2.13 (A0), U3.4 (V-)
GND_R: BAT_HOLE-101.1, C101.2, C102.2, C103.2, DISP101.4 (GND), J101.B, R105.2, R106.2, R107.2, R108.2, R109.2, R111.2, R112.2, RSW101.2, SW101.3 (SG), SW102.3 (SG), SW103.3 (SG), SW104.3 (SG), SW105.3 (SG), SW106.3 (SG), SW107.3 (SG), SW108.3 (SG), SW109.3 (SG), SW110.3 (SG), SW111.3 (SG), SW112.3 (SG), SW113.3 (SG), SW114.3 (SG), SW115.3 (SG), SW116.3 (SG), SW117.3 (SG), U101.3 (GND), U101.4 (GND), U101.23 (GND), U102.7 (VEE), U102.8 (GND), U102.12 (A3), U102.13 (A0), U102.14 (A1), U103.4 (V-)
HAND: R12.1, U1.2 (RX1/D2)
HAND_R: R112.1, U101.2 (RX1/D2)
MOSI: DISP1.1 (MOSI), U1.5 (2/D1/SDA)
MOSI_R: DISP101.1 (MOSI), U101.5 (2/D1/SDA)
unnamed: JP1.1 (A), R10.1, R11.1, U3.2 (IN-)
unnamed: JP101.1 (A), R110.1, R111.1, U103.2 (IN-)
unnamed: R1.1, SW1.2, SW2.2, SW3.2, SW4.2, SW5.2
unnamed: R2.2, SW6.2, SW7.2, SW8.2, SW9.2, SW10.2
unnamed: R3.2, SW11.2, SW12.2, SW13.2, SW14.2, SW15.2
unnamed: R4.2, SW16.2, SW17.2
unnamed: R101.1, SW101.2, SW102.2, SW103.2, SW104.2, SW105.2
unnamed: R102.2, SW106.2, SW107.2, SW108.2, SW109.2, SW110.2
unnamed: R103.2, SW111.2, SW112.2, SW113.2, SW114.2, SW115.2
unnamed: R104.2, SW116.2, SW117.2
POWER: C1.1, C3.1, U1.16 (B1/15), U2.16 (VCC), U3.7 (V+)
POWER_R: C101.1, C103.1, U101.8 (5/C6), U102.16 (VCC), U103.7 (V+)
RAW: PSW1.3 (C), U1.24 (RAW)
RAW_R: PSW101.3 (C), U101.24 (RAW)
RESET: RSW1.1, U1.22 (RST)
RESET_R: RSW101.1, U101.22 (RST)
ROW0: R1.2, U1.7 (4/D4)
ROW0_R: R101.2, U101.20 (F4/A3)
ROW1: R2.1, U1.8 (5/C6)
ROW1_R: R102.1, U101.19 (F5/A2)
ROW2: R3.1, U1.9 (6/D7)
ROW2_R: R103.1, U101.17 (F7/A0)
ROW3: R4.1, U1.14 (B2/16)
ROW3_R: R104.1, U101.15 (B3/14)
SCK: DISP1.2 (SCK), U1.6 (3/D0/SCL)
SCK_R: DISP101.2 (SCK), U101.6 (3/D0/SCL)

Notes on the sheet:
Display
OpAmp
MUX
RESET
Matrix
TRRS
Battery
MCU

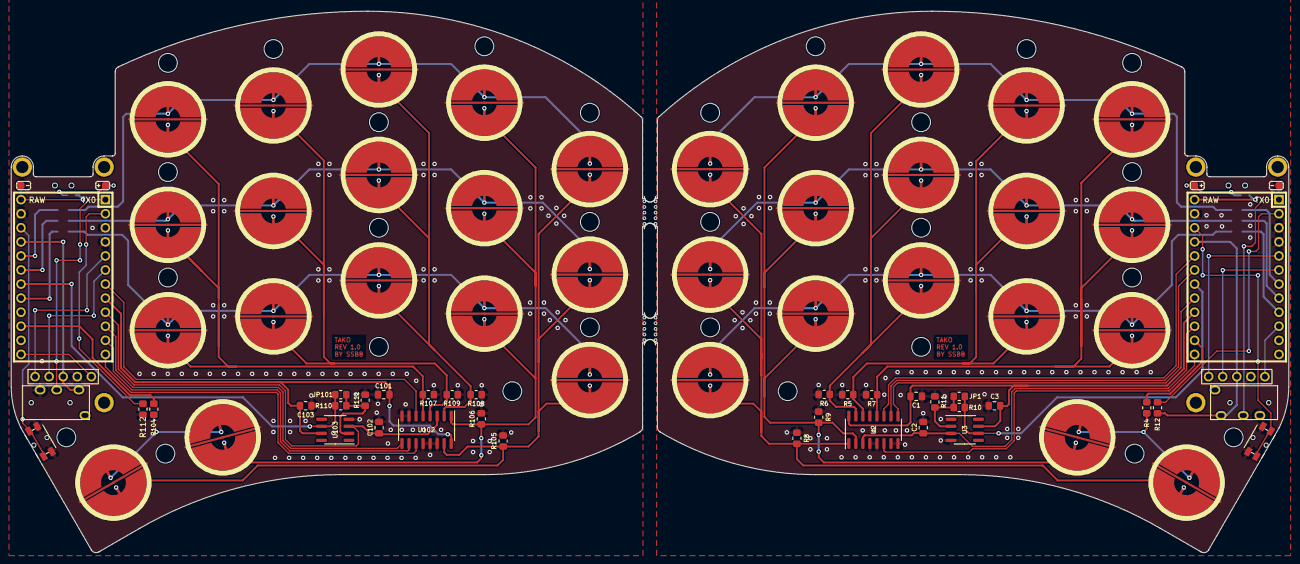
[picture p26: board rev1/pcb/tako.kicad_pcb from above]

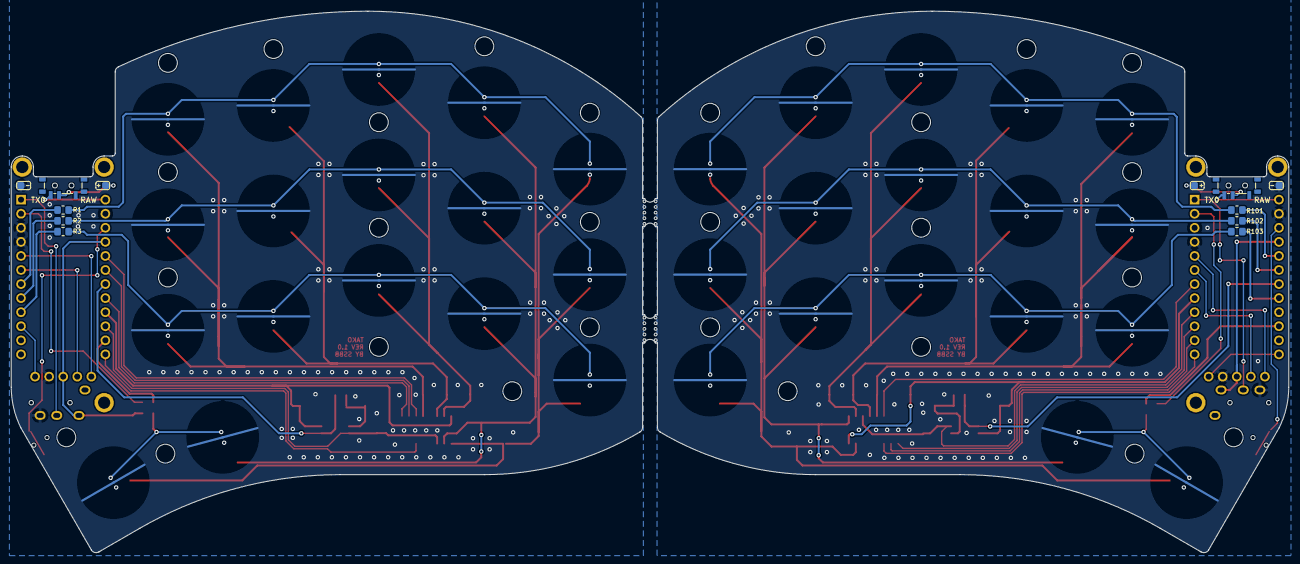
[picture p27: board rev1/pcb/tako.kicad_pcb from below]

Board: 2 copper layers, 230.7 x 97.8 mm, 120 parts (10 on the bottom side), 62 nets.

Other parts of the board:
mouse-bite-2mm-slot, mouse-bite-2mm-slot#2: VAL**; mouse-bite-5mm-slot-with-space-for-track

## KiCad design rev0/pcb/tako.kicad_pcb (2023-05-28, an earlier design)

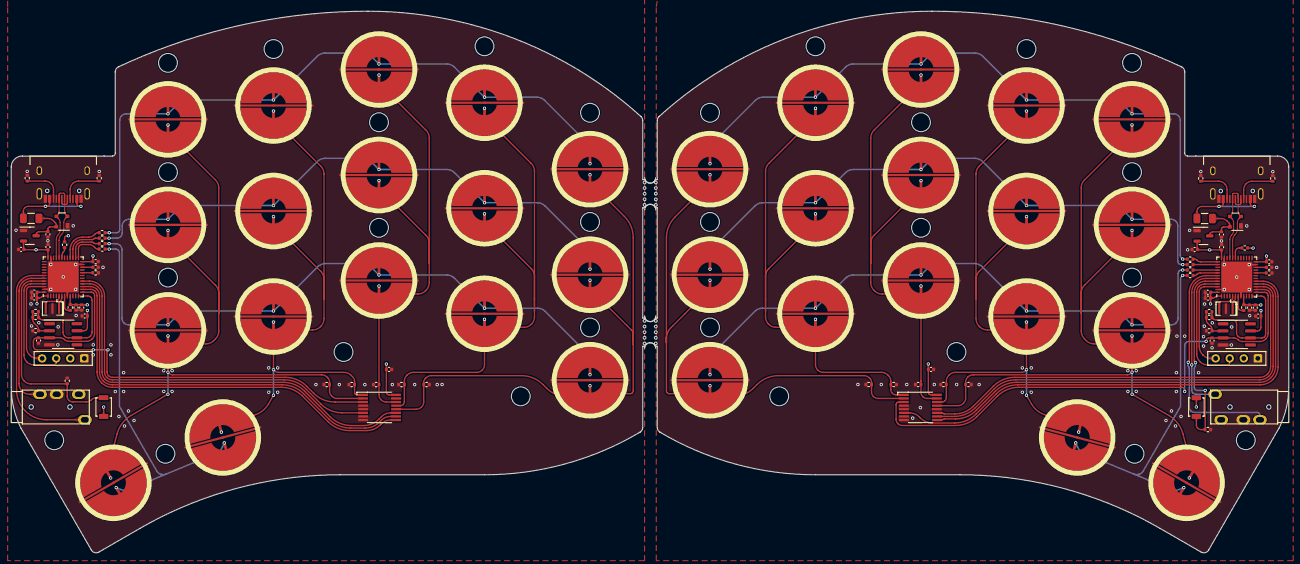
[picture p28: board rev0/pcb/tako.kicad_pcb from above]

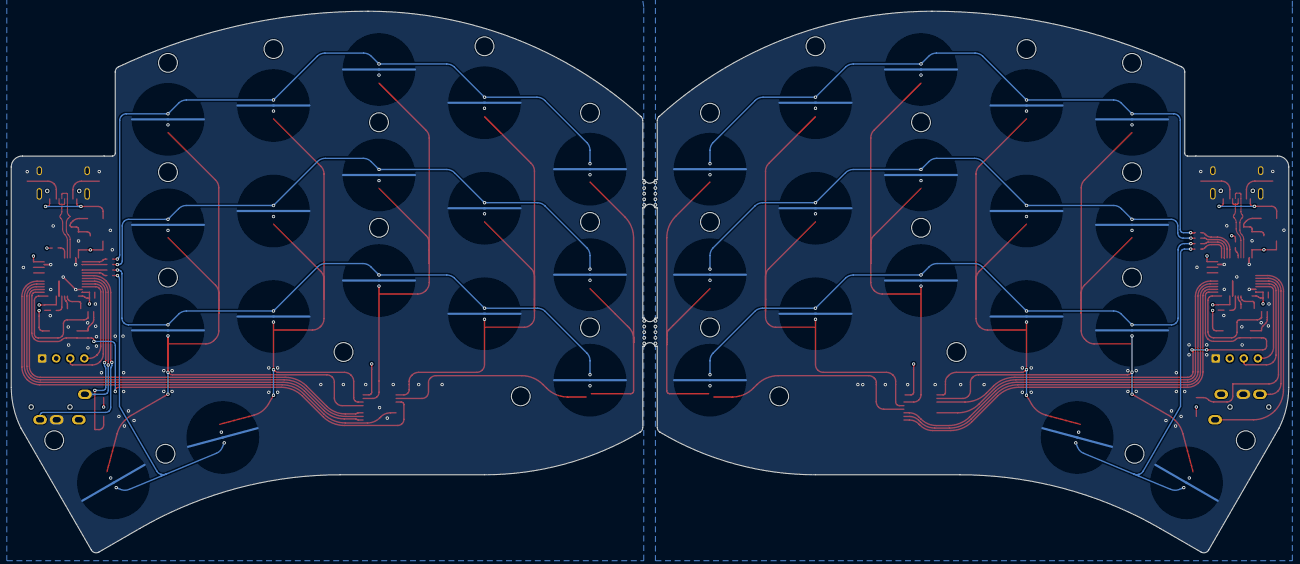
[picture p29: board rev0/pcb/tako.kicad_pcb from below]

Board: 4 copper layers, 230.7 x 97.8 mm, 146 parts (14 on the bottom side), 78 nets.

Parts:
C1, C2, C8, C101, C102, C108: 1u; C_0402_1005Metric
C3, C4, C5, C6, C7, C10, C12, C103, C104, C105, C106, C107, C110, C112: 100n; C_0402_1005Metric
C9, C109: 4.7u; C_0402_1005Metric
C11, C111: 220p; C_0402_1005Metric
D1, D101: PRTR5V0U2X; SOT-143
F1, F101: 500mA; Fuse_1206_3216Metric
H1, H2, H3, H4, H5, H6, H7, H8, H9, H10, H11, H12, H13, H14, H101, H102, H103, H104, H105, H106, H107, H108, H109, H110, H111, H112, H113, H114: MountingHole; MountingHole_3.4mm
J1, J101: MJ-4PP-9; TRRS-PJ-320A-no-Fmask
J2, J102: OLED; OLED_I2C_128x32
JP1, JP101: BOOT0; SW_SPST_B3U-1000P
JP2, JP102: Ext_Res; R_0402_1005Metric
R1, R2, R101, R102: 5.1k; R_0402_1005Metric
R3, R11, R13, R14, R15, R16, R17, R103, R111, R113, R114, R115, R116, R117: 100k; R_0402_1005Metric
R4, R5, R6, R7, R104, R105, R106, R107: 100; R_0402_1005Metric
R8, R9, R10, R108, R109, R110: 10k; R_0402_1005Metric
R12, R112: 1k; R_0402_1005Metric
SW1, SW2, SW3, SW4, SW5, SW6, SW7, SW8, SW9, SW10, SW11, SW12, SW13, SW14, SW15, SW101, SW102, SW103, SW104, SW105, SW106, SW107, SW108, SW109, SW110, SW111, SW112, SW113, SW114, SW115: EC_SW; ecs_pad_1U_no_ring
SW16, SW17, SW116, SW117: EC_SW; ecs_pad_1U_no_ring_90deg
U1, U101: STM32F401CBUx; QFN-48-1EP_7x7mm_P0.5mm_EP5.6x5.6mm
U2, U102: XC6206PxxxMR; SOT-23-3
U3, U103: OPA350; SOIC-8_3.9x4.9mm_P1.27mm
U4, U104: 74HC4051; TSSOP16
USB1, USB101: TYPEC-304YSSW-ACP16; HRO-TYPE-C-31-M-12-Assembly
Y1, Y101: 8 MHz; Resonator_SMD_Murata_CSTxExxV-3Pin_3.0x1.1mm
mouse-bite-2mm-slot, mouse-bite-2mm-slot#2: VAL**; mouse-bite-5mm-slot-with-space-for-track

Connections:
+5V: C1.1, D1.4 (VCC), F1.2, U2.3 (VI)
+5V_R: C101.1, D101.4 (VCC), F101.2, U102.3 (VI)
ADC: JP2.1 (A), R11.2, U1.12 (PA2), U3.6 (OUT)
ADC_R: JP102.1 (A), R111.2, U101.12 (PA2), U103.6 (OUT)
AMUX_SEL_0: U1.14 (PA4), U4.11 (S0)
AMUX_SEL_0_R: U101.16 (PA6), U104.11 (S0)
AMUX_SEL_1: U1.15 (PA5), U4.10 (S1)
AMUX_SEL_1_R: U101.15 (PA5), U104.10 (S1)
AMUX_SEL_2: U1.16 (PA6), U4.9 (S2)
AMUX_SEL_2_R: U101.14 (PA4), U104.9 (S2)
APLEX_EN_PIN_0: U1.17 (PA7), U4.6 (~E)
APLEX_EN_PIN_0_R: U101.17 (PA7), U104.6 (~E)
APLEX_OUT_PIN_0: C11.2, U1.13 (PA3), U3.3 (IN+), U4.3 (A)
APLEX_OUT_PIN_0_R: C111.2, U101.13 (PA3), U103.3 (IN+), U104.3 (A)
BOOT0: JP1.1 (A), R10.1, U1.44 (BOOT0)
BOOT0_R: JP101.1 (A), R110.1, U101.44 (BOOT0)
BOOT1: R9.1, U1.20 (PB2)
BOOT1_R: R109.1, U101.20 (PB2)
COL0: R17.1, SW1.1, SW6.1, SW11.1, U4.2 (A6)
COL0_R: R115.1, SW101.1, SW106.1, SW111.1, U104.12 (A3)
COL1: R16.1, SW2.1, SW7.1, SW12.1, U4.1 (A4)
COL1_R: R113.1, SW102.1, SW107.1, SW112.1, U104.13 (A0)
COL2: R15.1, SW3.1, SW8.1, SW13.1, U4.15 (A2)
COL2_R: R114.1, SW103.1, SW108.1, SW113.1, U104.14 (A1)
COL3: R14.1, SW4.1, SW9.1, SW14.1, SW16.1, U4.14 (A1)
COL3_R: R116.1, SW104.1, SW109.1, SW114.1, SW116.1, U104.1 (A4)
COL4: R13.1, SW5.1, SW10.1, SW15.1, SW17.1, U4.13 (A0)
COL4_R: R117.1, SW105.1, SW110.1, SW115.1, SW117.1, U104.2 (A6)
D+: D1.3 (I/O2), U1.33 (PA12), USB1.6 (DP1), USB1.8 (DP2)
D+_R: D101.3 (I/O2), U101.33 (PA12), USB101.6 (DP1), USB101.8 (DP2)
D-: D1.2 (I/O1), U1.32 (PA11), USB1.5 (DN2), USB1.7 (DN1)
D-_R: D101.2 (I/O1), U101.32 (PA11), USB101.5 (DN2), USB101.7 (DN1)
GND: C1.2, C2.2, C3.2, C4.2, C5.2, C6.2, C7.2, C8.2, C9.2, C10.2, C11.1, C12.2, D1.1 (GND), J1.C, J2.1, R1.1, R2.2, R9.2, R10.2, R12.1, R13.2, R14.2, R15.2, R16.2, R17.2, SW1.3 (SG), SW2.3 (SG), SW3.3 (SG), SW4.3 (SG), SW5.3 (SG), SW6.3 (SG), SW7.3 (SG), SW8.3 (SG), SW9.3 (SG), SW10.3 (SG), SW11.3 (SG), SW12.3 (SG), SW13.3 (SG), SW14.3 (SG), SW15.3 (SG), SW16.3 (SG), SW17.3 (SG), U1.8 (VSSA), U1.23 (VSS), U1.35 (VSS), U1.47 (VSS), U1.49 (VSS), U2.1 (GND), U3.4 (V-), U4.4 (A7), U4.5 (A5), U4.7 (VEE), U4.8 (GND), U4.12 (A3), USB1.1 (GND), USB1.12 (GND), USB1.13 (SHIELD), Y1.2
GND_R: C101.2, C102.2, C103.2, C104.2, C105.2, C106.2, C107.2, C108.2, C109.2, C110.2, C111.1, C112.2, D101.1 (GND), J101.C, J102.1, R101.1, R102.2, R109.2, R110.2, R112.1, R113.2, R114.2, R115.2, R116.2, R117.2, SW101.3 (SG), SW102.3 (SG), SW103.3 (SG), SW104.3 (SG), SW105.3 (SG), SW106.3 (SG), SW107.3 (SG), SW108.3 (SG), SW109.3 (SG), SW110.3 (SG), SW111.3 (SG), SW112.3 (SG), SW113.3 (SG), SW114.3 (SG), SW115.3 (SG), SW116.3 (SG), SW117.3 (SG), U101.8 (VSSA), U101.23 (VSS), U101.35 (VSS), U101.47 (VSS), U101.49 (VSS), U102.1 (GND), U103.4 (V-), U104.4 (A7), U104.5 (A5), U104.7 (VEE), U104.8 (GND), U104.15 (A2), USB101.1 (GND), USB101.12 (GND), USB101.13 (SHIELD), Y101.2
NRST: R8.2, U1.7 (NRST)
NRST_R: R108.2, U101.7 (NRST)
unnamed: JP2.2 (B), R11.1, R12.2, U3.2 (IN-)
unnamed: JP102.2 (B), R111.1, R112.2, U103.2 (IN-)
unnamed: R3.1, U1.31 (PA10)
unnamed: R4.1, U1.37 (PA14)
unnamed: R5.1, U1.38 (PA15)
unnamed: R6.2, U1.40 (PB4)
unnamed: R7.1, U1.41 (PB5)
unnamed: C9.1, U1.22 (VCAP1)
unnamed: R103.1, U101.31 (PA10)
unnamed: R104.1, U101.25 (PB12)
unnamed: R105.2, U101.26 (PB13)
unnamed: R106.1, U101.27 (PB14)
unnamed: R107.1, U101.28 (PB15)
unnamed: C109.1, U101.22 (VCAP1)
unnamed: R1.2, USB1.4 (CC1)
unnamed: R2.1, USB1.10 (CC2)
unnamed: R101.2, USB101.4 (CC1)
unnamed: R102.1, USB101.10 (CC2)
ROW0: R4.2, SW1.2, SW2.2, SW3.2, SW4.2, SW5.2
ROW0_R: R107.2, SW101.2, SW102.2, SW103.2, SW104.2, SW105.2
ROW1: R5.2, SW6.2, SW7.2, SW8.2, SW9.2, SW10.2
ROW1_R: R106.2, SW106.2, SW107.2, SW108.2, SW109.2, SW110.2
ROW2: R6.1, SW11.2, SW12.2, SW13.2, SW14.2, SW15.2
ROW2_R: R105.1, SW111.2, SW112.2, SW113.2, SW114.2, SW115.2
ROW3: R7.2, SW16.2, SW17.2
ROW3_R: R104.2, SW116.2, SW117.2
RX: J1.A, U1.43 (PB7)
RX_R: J101.B, U101.43 (PB7)
SCL: J2.3, U1.45 (PB8)
SCL_R: J102.3, U101.45 (PB8)
SDA: J2.4, U1.46 (PB9)
SDA_R: J102.4, U101.46 (PB9)
TX: J1.B, U1.42 (PB6)
TX_R: J101.A, U101.42 (PB6)
VBAT: C2.1, C3.1, C4.1, C5.1, C6.1, C7.1, C8.1, C10.1, C12.1, J1.D, J2.2, JP1.2 (B), R3.2, R8.1, U1.1 (VBAT), U1.9 (VREF+), U1.24 (VDD), U1.36 (VDD), U1.48 (VDD), U2.2 (VO), U3.7 (V+), U4.16 (VCC)
VBAT_R: C102.1, C103.1, C104.1, C105.1, C106.1, C107.1, C108.1, C110.1, C112.1, J101.D, J102.2, JP101.2 (B), R103.2, R108.1, U101.1 (VBAT), U101.9 (VREF+), U101.24 (VDD), U101.36 (VDD), U101.48 (VDD), U102.2 (VO), U103.7 (V+), U104.16 (VCC)
VBUS: F1.1, USB1.2 (VBUS), USB1.11 (VBUS)
VBUS_R: F101.1, USB101.2 (VBUS), USB101.11 (VBUS)
XTAL0: U1.5 (PH0), Y1.3
XTAL0_R: U101.5 (PH0), Y101.3
XTAL1: U1.6 (PH1), Y1.1
XTAL1_R: U101.6 (PH1), Y101.1

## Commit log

2023-05-12 Add PCB
    [bottom-plate.kicad_pcb, tako.kicad_pcb, tako.kicad_sch]
2023-05-12 move pcb to it's own dir
    [bottom-plate.kicad_pcb, tako.kicad_pcb, tako.kicad_sch]
2023-05-12 Fix mounting holes and add bottom plate cutouts
    [bottom-plate.kicad_pcb, tako.kicad_pcb]
2023-05-13 Add BOM
2023-05-13 Add warning and fix BOM title
2023-05-13 FIx top plate warning
2023-05-13 Add oled to BOM
2023-05-13 Move top plate warning to assembled section
2023-05-13 Get rid of old name
    [bottom-plate.kicad_pcb, tako.kicad_pcb, tako.kicad_sch]
2023-05-13 Fix volacano springs notice
2023-05-14 Add standoff OD warning
2023-05-14 Add standoff links
2023-05-14 Move optional mounting to it's own section
2023-05-14 Fix m2 screw size
2023-05-14 Fix exta mounting text
2023-05-14 Fix grammar on optional mounting
2023-05-14 Bold top plate thickness warning
2023-05-14 Change top plate warn
2023-05-14 Add springs used
2023-05-17 Add firmware
    [bottom-plate.kicad_pcb, tako.kicad_pcb, tako.kicad_sch]
2023-05-18 Move notes up in bom
2023-05-23 Hotfix bottom plate
    [bottom-plate.kicad_pcb]
2023-05-23 Add warn to the guide for wrong bottom plate
2023-05-28 Remove sentence about possibility to use oem topre sliders with different plate
2023-05-28 Align mounting holes to by in sync with diy version
    [bottom-plate.kicad_pcb, tako.kicad_pcb]
2023-05-28 Add a link to assembled version firmware
2023-05-28 Add bottom plate fix guide
2023-05-28 Move trrs socket warning to the start of section
2023-09-09 Move rev0 to it's own dir
    [bottom-plate.kicad_pcb, tako.kicad_pcb, tako.kicad_sch]
2023-09-09 Move plates
    [bottom-plate.kicad_pcb]
2023-09-09 Add rev1 source files
    [bottom-plate.kicad_pcb, bottom_plate.kicad_pcb, tako.kicad_pcb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]
2023-09-09 Move niz plates to correct directory
    [top_plate_niz.kicad_pcb]
2023-09-09 Fix plate footprint libs
2023-09-09 Fix BOM table
2023-09-09 Re-order BOM
2023-09-09 Do not use bold font for BOM
2023-09-09 Do not use caps for bom
2023-09-09 Try to use pcb
2023-09-09 Expose bat pads on both front and back sides
    [tako.kicad_pcb]
2023-09-10 Fix mounting links
2023-09-10 Add wireless note to readme
2023-09-10 Add plates warn
2023-09-10 Add build guide components section
    [tako.kicad_pcb, tako.kicad_sch]
2023-09-10 Add top plate section
2023-09-10 Add top plate domes section
2023-09-10 Add final assembly section
2023-09-10 Prepare gerbers
    [bottom_plate.kicad_pcb, tako.kicad_pcb, top_plate.kicad_pcb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]
2023-10-23 List specific standoffs
2023-10-23 Add standoff max od note
2026-06-19 Add the case to readme
